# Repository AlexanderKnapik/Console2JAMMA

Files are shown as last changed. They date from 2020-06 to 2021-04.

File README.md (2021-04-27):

# Console2JAMMA

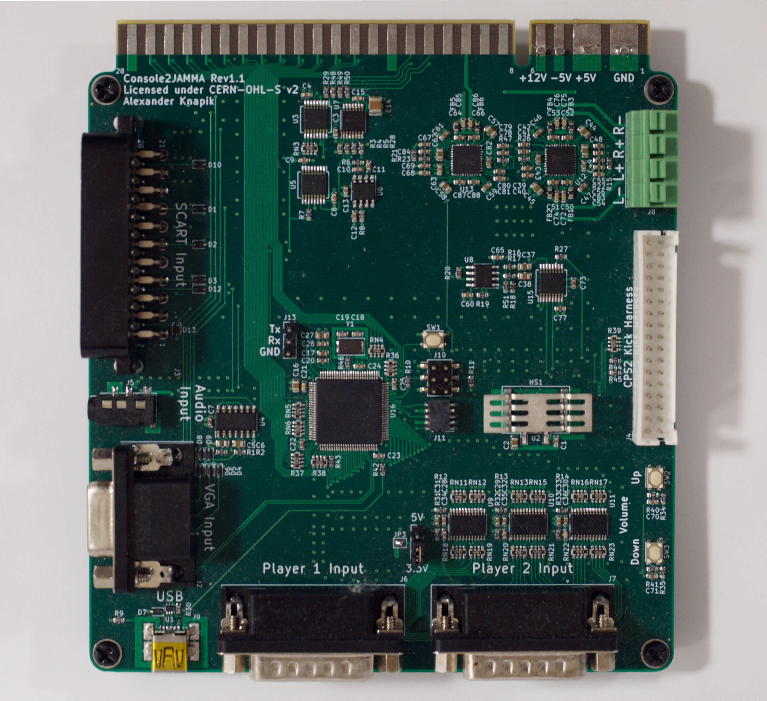
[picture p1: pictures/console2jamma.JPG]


A system to plug video game consoles into a JAMMA arcade system. 

## Features & Goals
- SCART based RGB or VGA video input. Will work perfectly with any natively RGB or modded console, including the Dreamcast. Handles any sync stripping and CSYNC combination for you with amplified video.
- Works with any arcade cabinet supporting standard JAMMA, "CHAMMA" and the CPS2 kick harness.
- Stereo audio input with selectable mono audio combiner for the JAMMA edge, or an external stereo audio output. Amplified for up to 5 Watts of power and can handle standard arcade 4 Ohm or 8 Ohm speakers.
- Can drive 2 player controller ports for 5V or 3.3V based consoles. Will work with any console that has 12 or fewer IO lines with a modded controller port extension.
- Handy spring terminal controller adapters available for those not comfortable with soldering.
- Single player USB output to support PS3 or XBox360 too.

## Progress
This is still heavily a work in progress. I've built up the first hardware prototype and identified some issues that I would like to address. However I am mainly still testing the hardware.

There is also no firmware currently written yet. This is what would need to be addressed next before any further hardware prototypes are designed.

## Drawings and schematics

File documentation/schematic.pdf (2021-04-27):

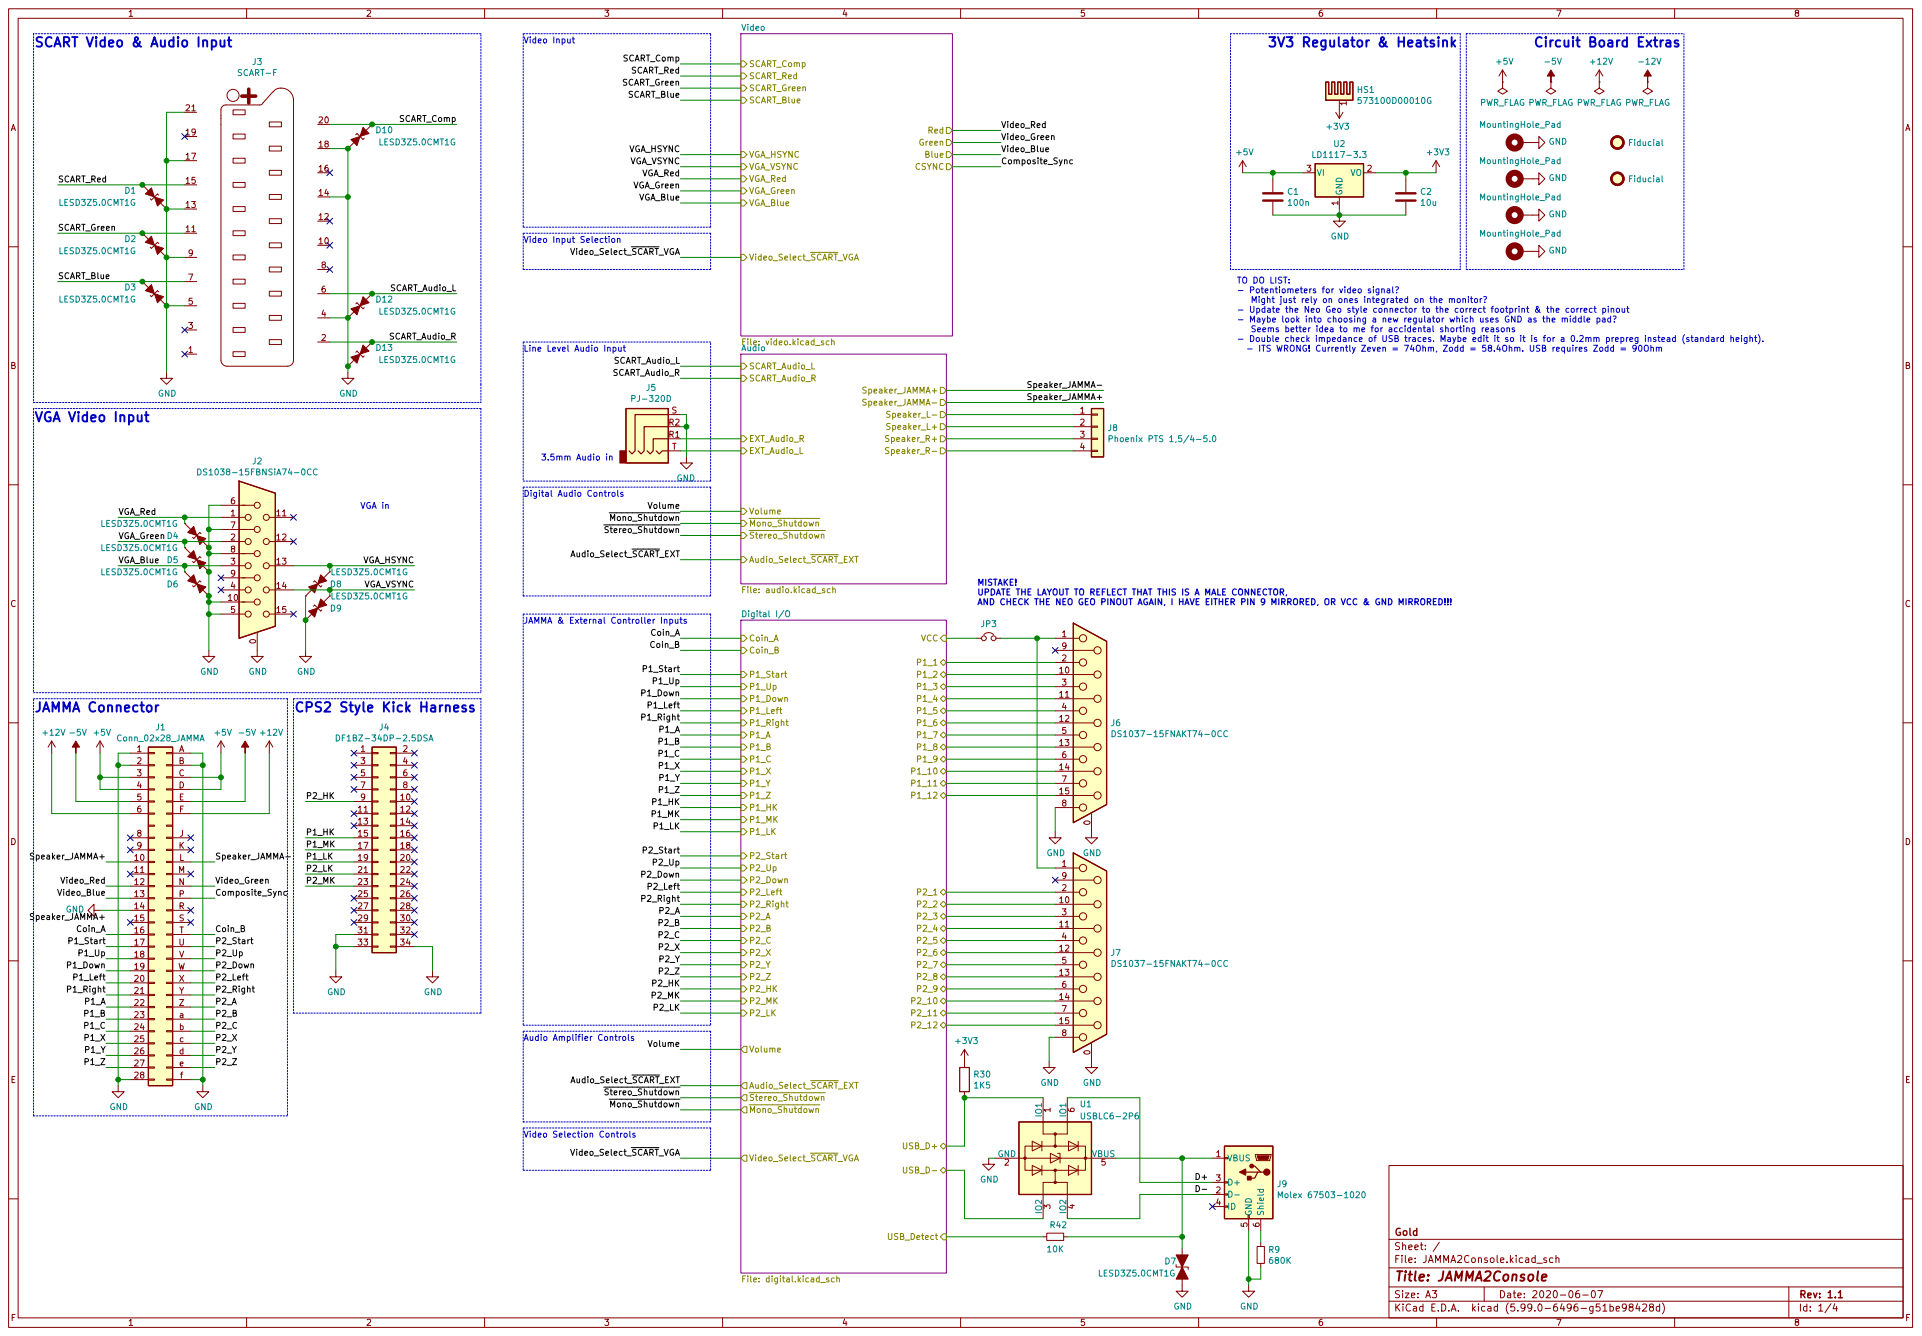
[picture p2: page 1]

TO DO LIST: - Potentiometers for video signal?

Might just rely on ones integrated on the monitor?
- Update the Neo Geo style connector to the correct footprint & the correct pinout
- Maybe look into choosing a new regulator which uses GND as the middle pad?
Seems better idea to me for accidental shorting reasons
- Double check impedance of USB traces. Maybe edit it so it is for a 0.2mm prepreg instead (standard height).
- ITS WRONG! Currently Zeven = 74Ohm, Zodd = 58.4Ohm. USB requires Zodd = 90Ohm

Line Level Audio Input

AND CHECK THE NEO GEO PINOUT AGAIN, I HAVE EITHER PIN 9 MIRRORED, OR VCC & GND MIRRORED!!! Video Selection Controls
JAMMA & External Controller Inputs

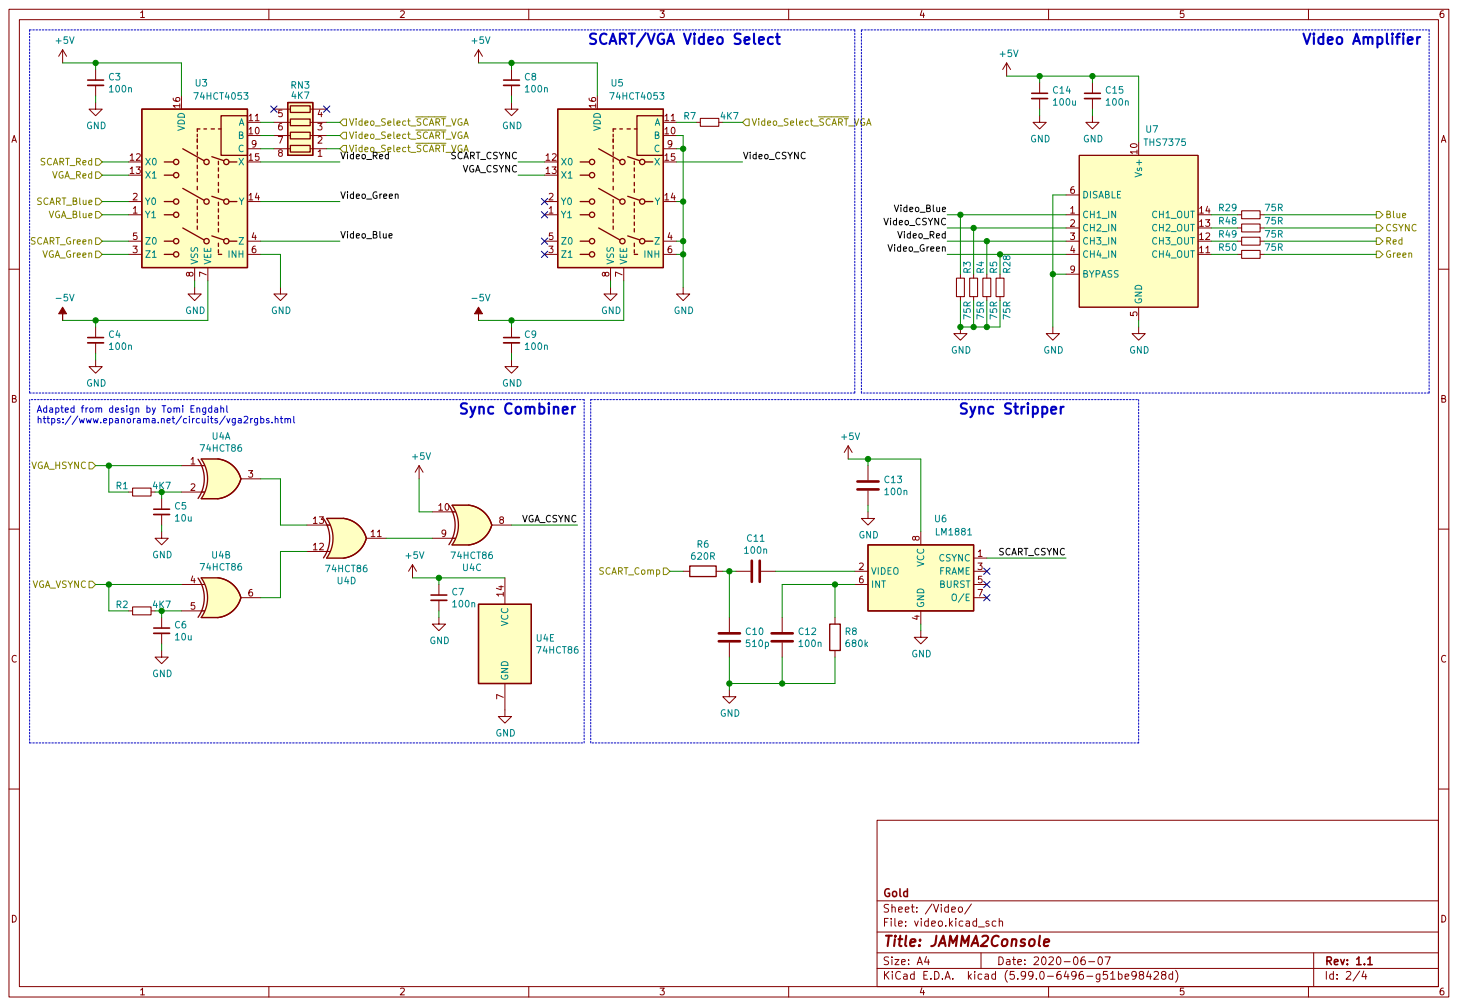
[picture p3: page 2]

SCART/VGA Video Select

Adapted from design by Tomi Engdahl
https://www.epanorama.net/circuits/vga2rgbs.html

File: video.kicad_sch Sheet: /Video/ Gold

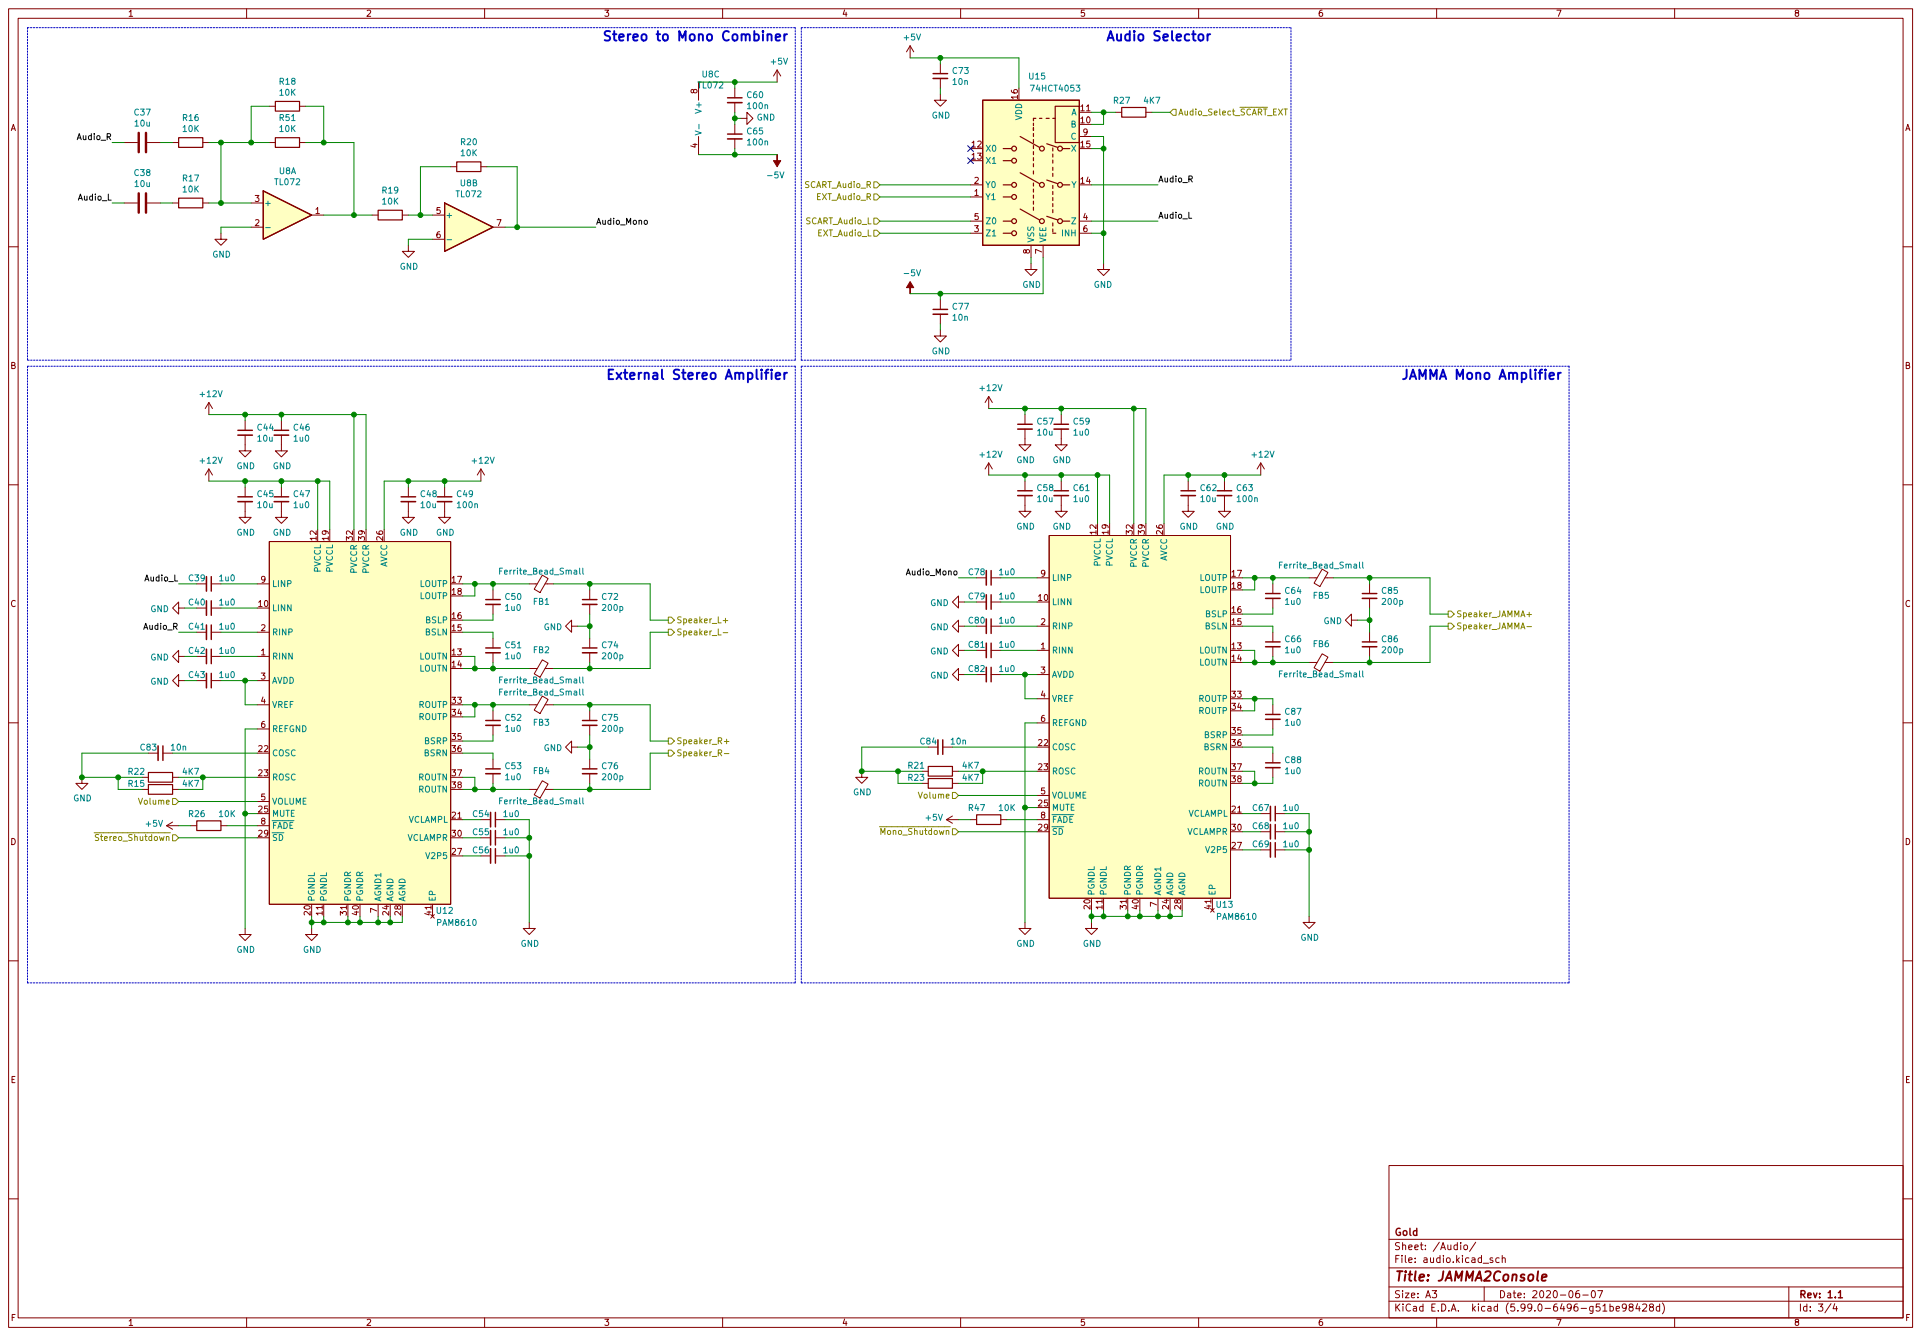
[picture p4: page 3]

File: audio.kicad_sch Sheet: /Audio/ Gold

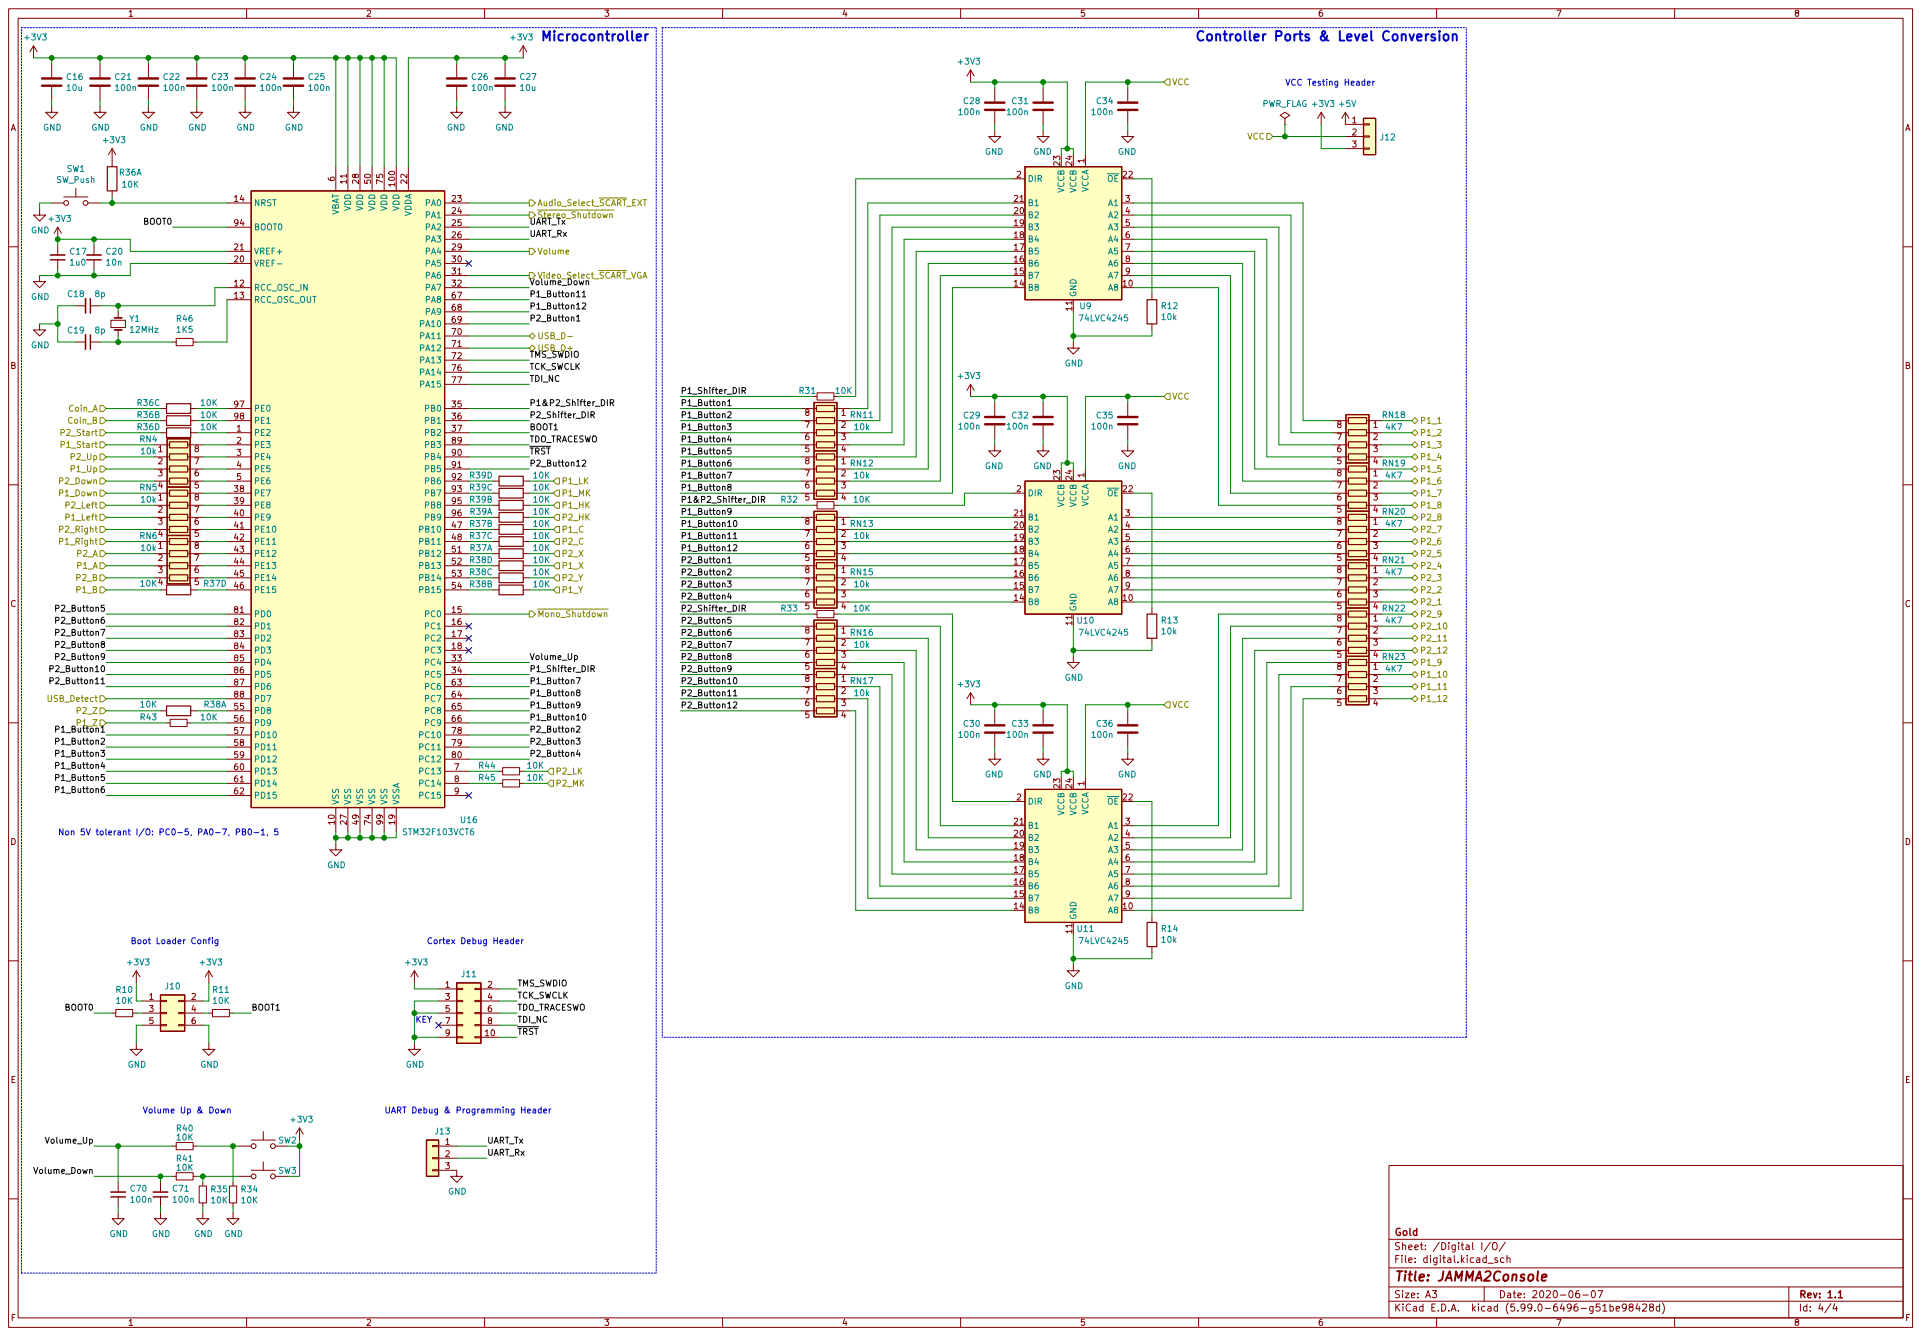
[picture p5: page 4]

Controller Ports & Level Conversion

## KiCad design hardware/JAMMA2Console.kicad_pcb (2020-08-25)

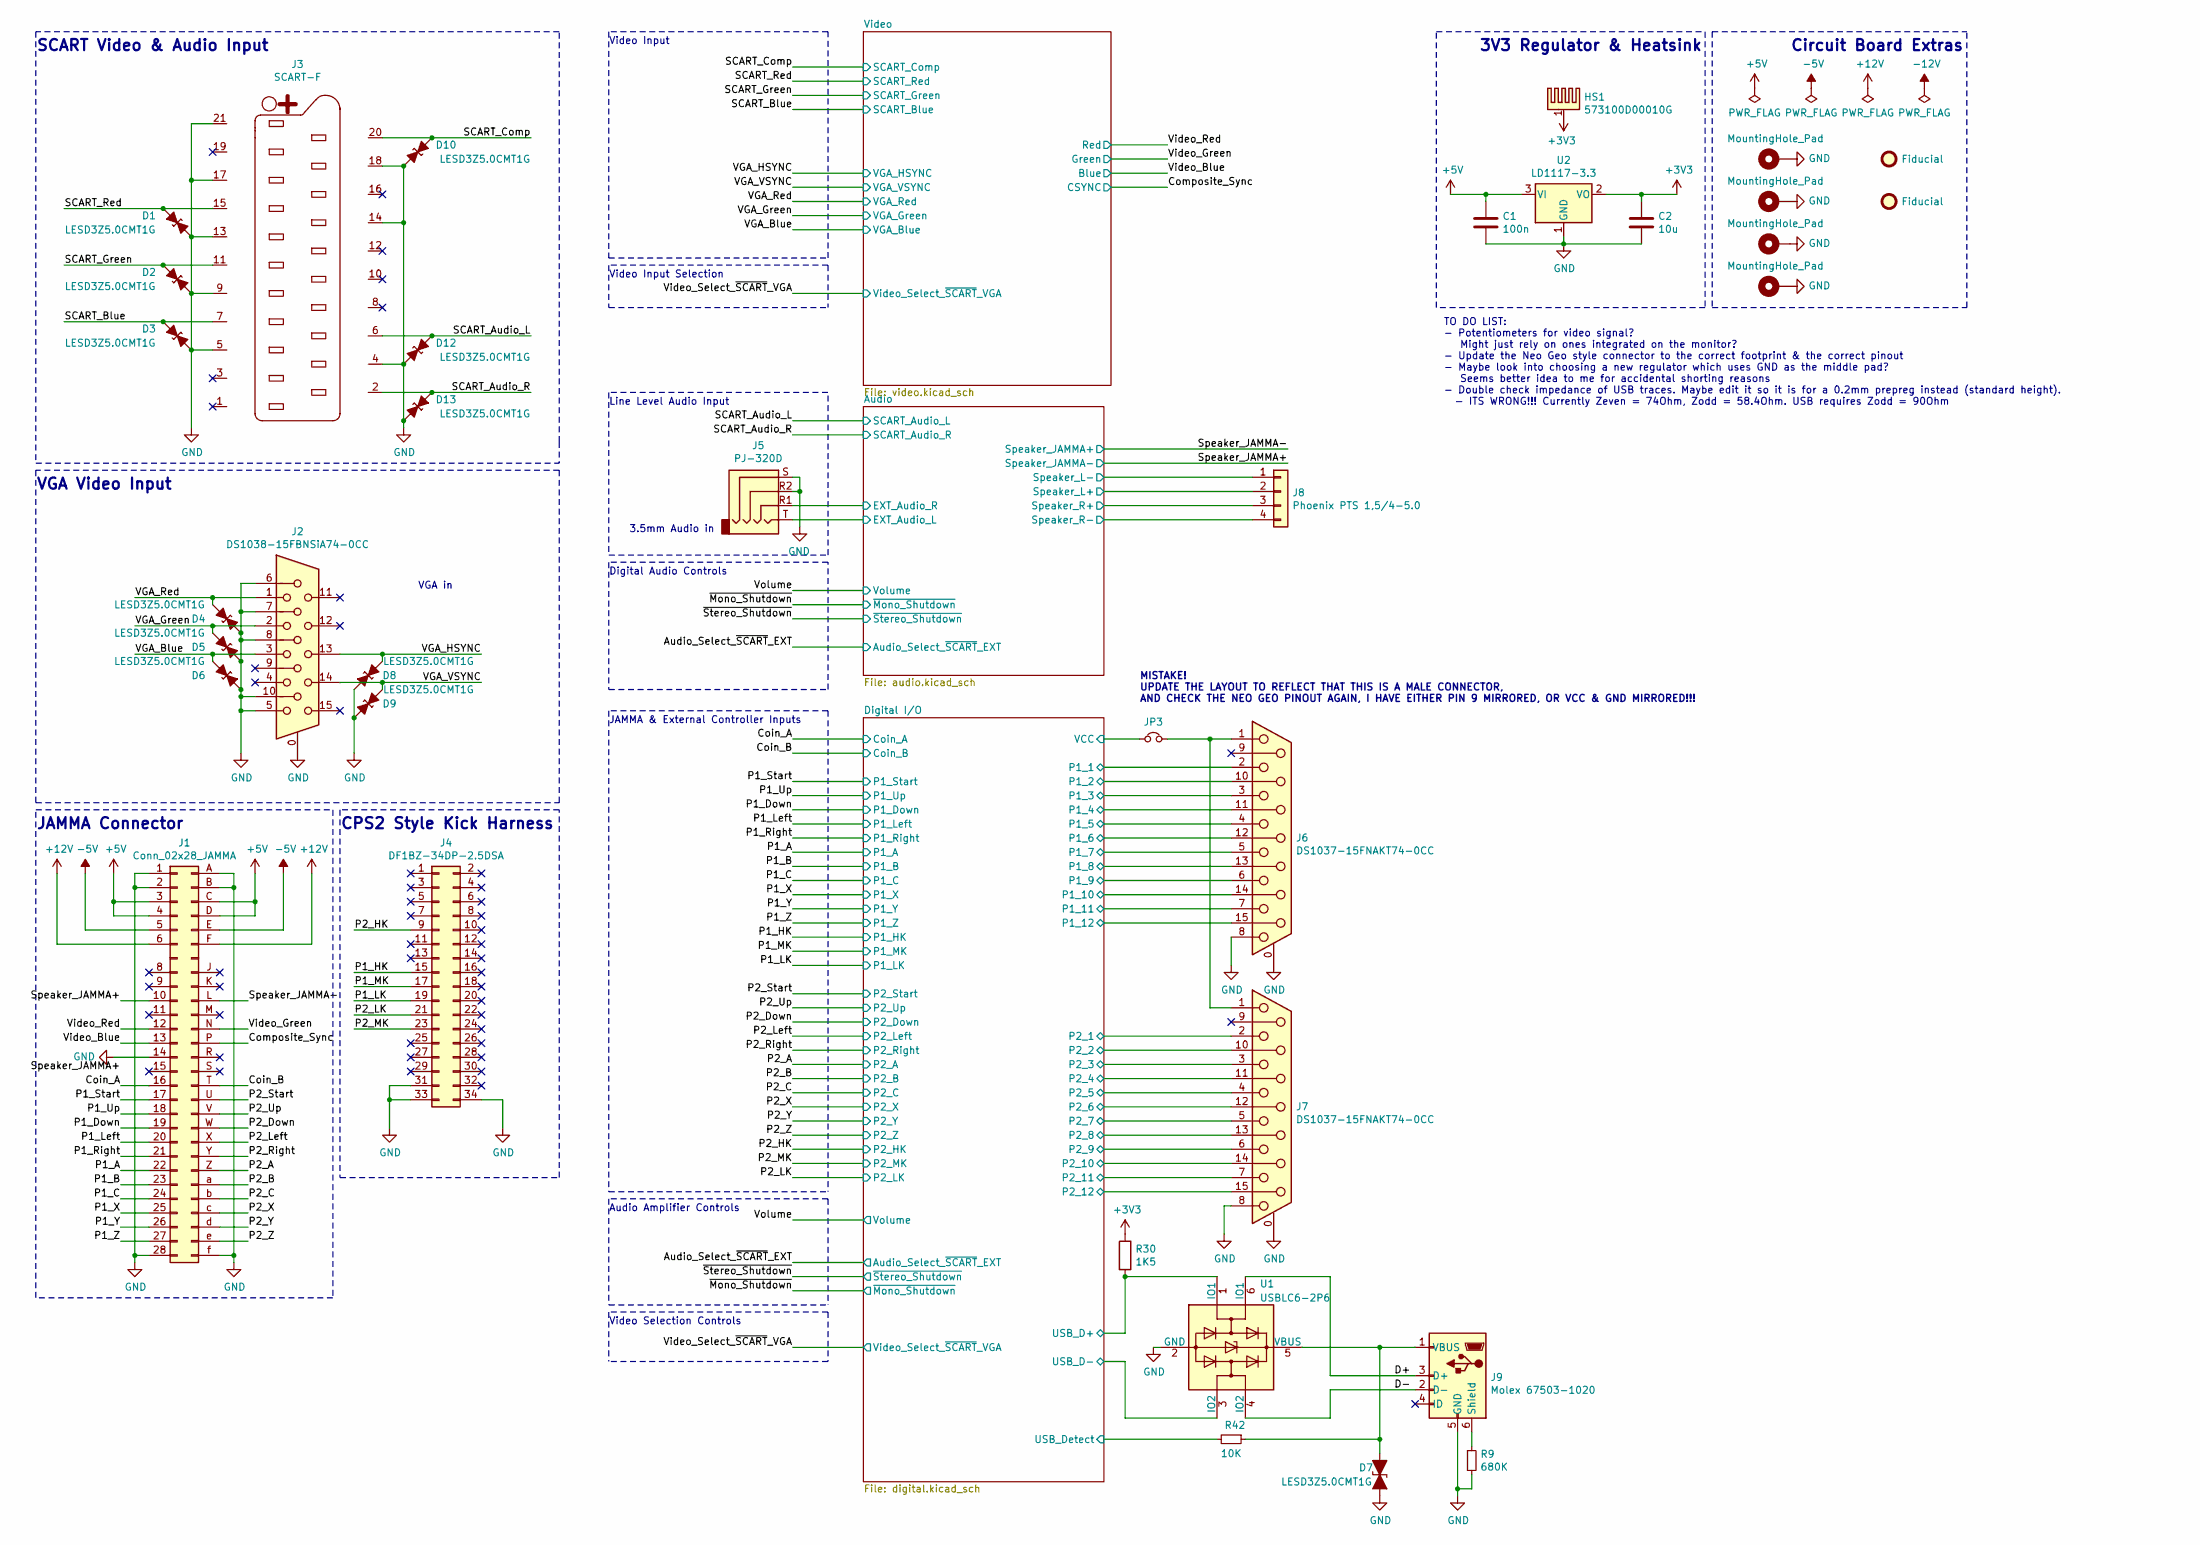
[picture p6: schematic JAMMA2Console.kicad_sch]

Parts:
C1: 100n; C_0603_1608Metric
C2: 10u; C_0805_2012Metric
D1, D2, D3, D4, D5, D6, D7, D8, D9, D10, D12, D13: LESD3Z5.0CMT1G; D_SOD-323
FID1, FID2: Fiducial; Fiducial_0.5mm_Mask1mm
H1, H2, H3, H4: MountingHole_Pad; MountingHole_3.2mm_M3_Pad_Via
HS1: 573100D00010G; Heatsink_AAVID_573100D000x0G_TO-252
J1: Conn_02x28_JAMMA; JAMMA_56_2x28_P3.96mm
J2: DS1038-15FBNSiA74-0CC; DSUB-15-HD_Female_Horizontal_P2.29x1.98mm_EdgePinOffset8.63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
J3: SCART-F; Conn_SCART_CS-107_Right_Angle_Female
J4: DF1BZ-34DP-2.5DSA; Conn_02x17_DF1BZ-34DP-2.5DSA
J5: PJ-320D; Jack_3.5mm_PJ320D_Horizontal
J6, J7: DS1037-15FNAKT74-0CC; DSUB-15_Female_Horizontal_P2.77x2.84mm_EdgePinOffset8.10mm_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
J8: Phoenix PTS 1,5/4-5.0; PhoenixContact_PTS_1,5_4-5_1x4_P5.00mm_Horizontal
J9: Molex 67503-1020; USB_Mini-B_Molex_657031020_Horizontal
JP3: Jumper_NC_Small; SolderJumper-2_P1.3mm_Open_TrianglePad1.0x1.5mm
R9: 680K; R_0603_1608Metric
R30: 1K5; R_0603_1608Metric
R42: 10K; R_0603_1608Metric
U1: USBLC6-2P6; SOT-666
U2: LD1117-3.3; TO-252-2

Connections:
+3V3: C2.1, HS1.1, R30.1, U2.2 (VO); also elsewhere on the board
+5V: C1.1, J1.3, J1.4, J1.C, J1.D, U2.3 (VI); also elsewhere on the board
+12V: J1.6, J1.F; also elsewhere on the board
-5V: J1.5, J1.E; also elsewhere on the board
/Coin_A: J1.16; also elsewhere on the board
/Coin_B: J1.T; also elsewhere on the board
/Composite_Sync: J1.P; also elsewhere on the board
/D+: J9.3 (D+), U1.6 (IO1)
/D-: J9.2 (D-), U1.4 (IO2)
/EXT_Audio_L: J5.T; also elsewhere on the board
/EXT_Audio_R: J5.R1; also elsewhere on the board
/P1_1: J6.2; also elsewhere on the board
/P1_2: J6.10; also elsewhere on the board
/P1_3: J6.3; also elsewhere on the board
/P1_4: J6.11 (P111); also elsewhere on the board
/P1_5: J6.4; also elsewhere on the board
/P1_6: J6.12; also elsewhere on the board
/P1_7: J6.5; also elsewhere on the board
/P1_8: J6.13; also elsewhere on the board
/P1_9: J6.6; also elsewhere on the board
/P1_10: J6.14; also elsewhere on the board
/P1_11: J6.7; also elsewhere on the board
/P1_12: J6.15; also elsewhere on the board
/P1_A: J1.22; also elsewhere on the board
/P1_B: J1.23; also elsewhere on the board
/P1_C: J1.24; also elsewhere on the board
/P1_Down: J1.19; also elsewhere on the board
/P1_HK: J4.15; also elsewhere on the board
/P1_LK: J4.19; also elsewhere on the board
/P1_Left: J1.20; also elsewhere on the board
/P1_MK: J4.17; also elsewhere on the board
/P1_Right: J1.21; also elsewhere on the board
/P1_Start: J1.17; also elsewhere on the board
/P1_Up: J1.18; also elsewhere on the board
/P1_X: J1.25; also elsewhere on the board
/P1_Y: J1.26; also elsewhere on the board
/P1_Z: J1.27; also elsewhere on the board
/P2_1: J7.2; also elsewhere on the board
/P2_2: J7.10; also elsewhere on the board
/P2_3: J7.3; also elsewhere on the board
/P2_4: J7.11 (P111); also elsewhere on the board
/P2_5: J7.4; also elsewhere on the board
/P2_6: J7.12; also elsewhere on the board
/P2_7: J7.5; also elsewhere on the board
/P2_8: J7.13; also elsewhere on the board
/P2_9: J7.6; also elsewhere on the board
/P2_10: J7.14; also elsewhere on the board
/P2_11: J7.7; also elsewhere on the board
/P2_12: J7.15; also elsewhere on the board
/P2_A: J1.Z; also elsewhere on the board
/P2_B: J1.a; also elsewhere on the board
/P2_C: J1.b; also elsewhere on the board
/P2_Down: J1.W; also elsewhere on the board
/P2_HK: J4.9; also elsewhere on the board
/P2_LK: J4.21; also elsewhere on the board
/P2_Left: J1.X; also elsewhere on the board
/P2_MK: J4.23; also elsewhere on the board
/P2_Right: J1.Y; also elsewhere on the board
/P2_Start: J1.U; also elsewhere on the board
/P2_Up: J1.V; also elsewhere on the board
/P2_X: J1.c; also elsewhere on the board
/P2_Y: J1.d; also elsewhere on the board
/P2_Z: J1.e; also elsewhere on the board
/SCART_Audio_L: D12.1, J3.6; also elsewhere on the board
/SCART_Audio_R: D13.1, J3.2; also elsewhere on the board
/SCART_Blue: D3.1, J3.7; also elsewhere on the board
/SCART_Comp: D10.1, J3.20; also elsewhere on the board
/SCART_Green: D2.1, J3.11; also elsewhere on the board
/SCART_Red: D1.1, J3.15; also elsewhere on the board
/Speaker_JAMMA+: J1.10; also elsewhere on the board
/Speaker_JAMMA-: J1.L; also elsewhere on the board
/Speaker_L+: J8.2; also elsewhere on the board
/Speaker_L-: J8.1; also elsewhere on the board
/Speaker_R+: J8.3; also elsewhere on the board
/Speaker_R-: J8.4; also elsewhere on the board
/USB_D+: R30.2, U1.1 (IO1); also elsewhere on the board
/USB_D-: U1.3 (IO2); also elsewhere on the board
/USB_Detect: R42.2; also elsewhere on the board
/VCC: JP3.2; also elsewhere on the board
/VGA_Blue: D6.2, J2.3; also elsewhere on the board
/VGA_Green: D5.2, J2.2; also elsewhere on the board
/VGA_HSYNC: D8.2, J2.13; also elsewhere on the board
/VGA_Red: D4.2, J2.1; also elsewhere on the board
/VGA_VSYNC: D9.2, J2.14; also elsewhere on the board
/Video_Blue: J1.13; also elsewhere on the board
/Video_Green: J1.N; also elsewhere on the board
/Video_Red: J1.12; also elsewhere on the board
GND: C1.2, C2.2, D1.2, D2.2, D3.2, D4.1, D5.1, D6.1, D7.2 (A2), D8.1, D9.1, D10.2, D12.2, D13.2, H1.1, H2.1, H3.1, H4.1, J1.1, J1.2, J1.14, J1.28, J1.A, J1.B, J1.f, J2.0, J2.5, J2.6, J2.7, J2.8, J2.10, J3.4, J3.5, J3.9, J3.13, J3.14, J3.17, J3.18, J3.21, J4.31, J4.33, J4.34, J5.R2, J5.S, J6.0 (PAD), J6.8, J7.0 (PAD), J7.8, J9.5 (GND), R9.2, U1.2 (GND), U2.1 (GND); also elsewhere on the board
unnamed: D7.1 (A1), J9.1 (VBUS), R42.1, U1.5 (VBUS)
unnamed: J6.1, J7.1, JP3.1
unnamed: J9.6 (Shield), R9.1

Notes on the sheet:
SCART Video & Audio Input
VGA Video Input
JAMMA Connector
CPS2 Style Kick Harness
VGA in
Video Input
Video Input Selection
Line Level Audio Input
Digital Audio Controls
JAMMA & External Controller Inputs
Audio Amplifier Controls
Video Selection Controls
3.5mm Audio in
MISTAKE! UPDATE THE LAYOUT TO REFLECT THAT THIS IS A MALE CONNECTOR, AND CHECK THE NEO GEO PINOUT AGAIN, I HAVE EITHER PIN 9 MIRRORED, OR VCC & GND MIRRORED!!!
TO DO LIST: - Potentiometers for video signal? Might just rely on ones integrated on the monitor? - Update the Neo Geo style connector to the correct footprint & the correct pinout - Maybe look into choosing a new regulator which uses GND as the middle pad? Seems better idea to me for accidental sh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
3V3 Regulator & Heatsink
Circuit Board Extras

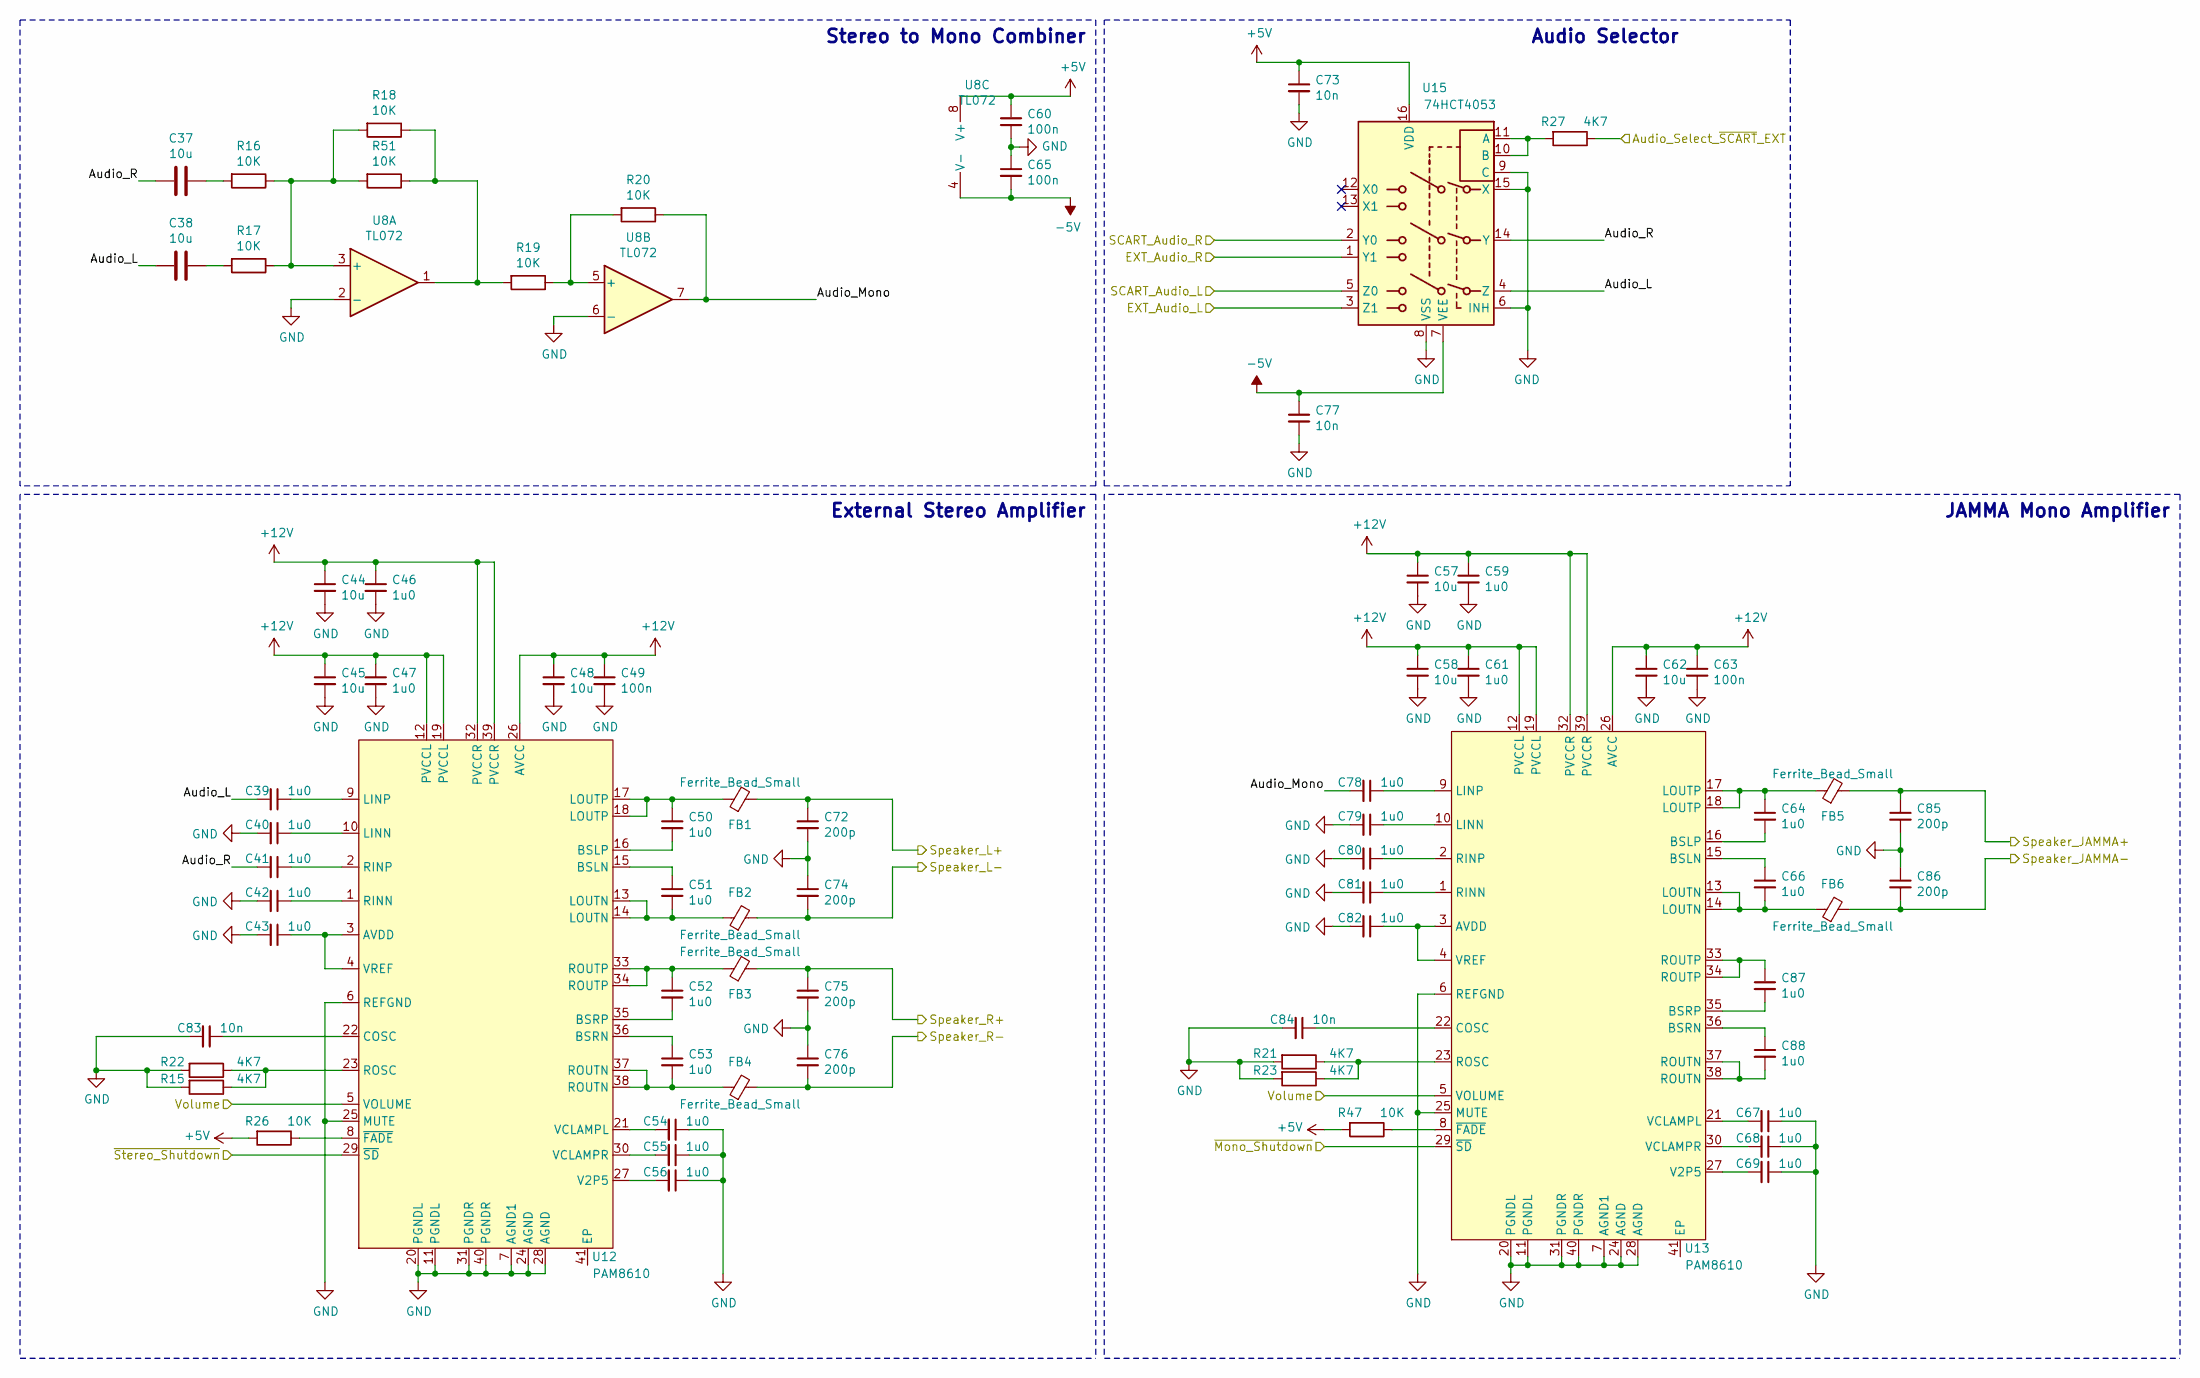
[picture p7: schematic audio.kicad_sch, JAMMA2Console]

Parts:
C37, C38, C44, C45, C48, C57, C58, C62: 10u; C_0805_2012Metric
C39, C40, C41, C42, C43, C46, C47, C50, C51, C52, C53, C54, C55, C56, C59, C61, C64, C66, C67, C68, C69, C78, C79, C80, C81, C82, C87, C88: 1u0; C_0603_1608Metric
C49, C60, C63, C65: 100n; C_0603_1608Metric
C72, C74, C75, C76, C85, C86: 200p; C_0603_1608Metric
C73, C77, C83, C84: 10n; C_0603_1608Metric
FB1, FB2, FB3, FB4, FB5, FB6: Ferrite_Bead_Small; L_0603_1608Metric
R15, R21, R22, R23, R27: 4K7; R_0603_1608Metric
R16, R17, R18, R19, R20, R26, R47, R51: 10K; R_0603_1608Metric
U8: TL072; SOIC-8_3.9x4.9mm_P1.27mm
U12, U13: PAM8610; QFN-40-1EP_6x6mm_P0.5mm_EP4.6x4.6mm_ThermalVias
U15: 74HCT4053; SSOP-16_5.3x6.2mm_P0.65mm

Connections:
+5V: C60.1, C73.1, R26.2, R47.2, U8.8 (V+), U15.16 (VDD); also elsewhere on the board
+12V: C44.1, C45.1, C46.1, C47.1, C48.1, C49.1, C57.1, C58.1, C59.1, C61.1, C62.1, C63.1, U12.12 (PVCCL), U12.19 (PVCCL), U12.26 (AVCC), U12.32 (PVCCR), U12.39 (PVCCR), U13.12 (PVCCL), U13.19 (PVCCL), U13.26 (AVCC), U13.32 (PVCCR), U13.39 (PVCCR); also elsewhere on the board
-5V: C65.2, C77.1, U8.4 (V-), U15.7 (VEE); also elsewhere on the board
/Audio/Audio_L: C38.2, C39.2, U15.4 (Z)
/Audio/Audio_Mono: C78.2, R20.1, U8.7
/Audio/Audio_R: C37.2, C41.2, U15.14 (Y)
/Audio_Select_~SCART~_EXT: R27.1; also elsewhere on the board
/EXT_Audio_L: U15.3 (Z1); also elsewhere on the board
/EXT_Audio_R: U15.1 (Y1); also elsewhere on the board
/SCART_Audio_L: U15.5 (Z0); also elsewhere on the board
/SCART_Audio_R: U15.2 (Y0); also elsewhere on the board
/Speaker_JAMMA+: C86.2, FB6.2; also elsewhere on the board
/Speaker_JAMMA-: C85.1, FB5.2; also elsewhere on the board
/Speaker_L+: C72.1, FB1.2; also elsewhere on the board
/Speaker_L-: C74.2, FB2.2; also elsewhere on the board
/Speaker_R+: C75.1, FB3.2; also elsewhere on the board
/Speaker_R-: C76.2, FB4.2; also elsewhere on the board
/Volume: U12.5 (VOLUME), U13.5 (VOLUME); also elsewhere on the board
/~Mono_Shutdown~: U13.29 (~SD~); also elsewhere on the board
/~Stereo_Shutdown~: U12.29 (~SD~); also elsewhere on the board
GND: C40.2, C42.2, C43.2, C44.2, C45.2, C46.2, C47.2, C48.2, C49.2, C54.1, C55.1, C56.1, C57.2, C58.2, C59.2, C60.2, C61.2, C62.2, C63.2, C65.1, C67.1, C68.1, C69.1, C72.2, C73.2, C74.1, C75.2, C76.1, C77.2, C79.2, C80.2, C81.2, C82.2, C83.2, C84.2, C85.2, C86.1, R15.2, R21.2, R22.2, R23.2, U8.2 (-), U8.6 (-), U12.6 (REFGND), U12.7 (AGND1), U12.11 (PGNDL), U12.20 (PGNDL), U12.24 (AGND), U12.25 (MUTE), U12.28 (AGND), U12.31 (PGNDR), U12.40 (PGNDR), U13.6 (REFGND), U13.7 (AGND1), U13.11 (PGNDL), U13.20 (PGNDL), U13.24 (AGND), U13.25 (MUTE), U13.28 (AGND), U13.31 (PGNDR), U13.40 (PGNDR), U15.6 (INH), U15.8 (VSS), U15.9 (C), U15.15 (X); also elsewhere on the board
unnamed: C37.1, R16.2
unnamed: C38.1, R17.2
unnamed: C39.1, U12.9 (LINP)
unnamed: C40.1, U12.10 (LINN)
unnamed: C41.1, U12.2 (RINP)
unnamed: C42.1, U12.1 (RINN)
unnamed: C43.1, U12.3 (AVDD), U12.4 (VREF)
unnamed: C50.1, FB1.1, U12.17 (LOUTP), U12.18 (LOUTP)
unnamed: C50.2, U12.16 (BSLP)
unnamed: C51.1, U12.15 (BSLN)
unnamed: C51.2, FB2.1, U12.13 (LOUTN), U12.14 (LOUTN)
unnamed: C52.1, FB3.1, U12.33 (ROUTP), U12.34 (ROUTP)
unnamed: C52.2, U12.35 (BSRP)
unnamed: C53.1, U12.36 (BSRN)
unnamed: C53.2, FB4.1, U12.37 (ROUTN), U12.38 (ROUTN)
unnamed: C54.2, U12.21 (VCLAMPL)
unnamed: C55.2, U12.30 (VCLAMPR)
unnamed: C56.2, U12.27 (V2P5)
unnamed: C64.1, FB5.1, U13.17 (LOUTP), U13.18 (LOUTP)
unnamed: C64.2, U13.16 (BSLP)
unnamed: C66.1, U13.15 (BSLN)
unnamed: C66.2, FB6.1, U13.13 (LOUTN), U13.14 (LOUTN)
unnamed: C67.2, U13.21 (VCLAMPL)
unnamed: C68.2, U13.30 (VCLAMPR)
unnamed: C69.2, U13.27 (V2P5)
unnamed: C78.1, U13.9 (LINP)
unnamed: C79.1, U13.10 (LINN)
unnamed: C80.1, U13.2 (RINP)
unnamed: C81.1, U13.1 (RINN)
unnamed: C82.1, U13.3 (AVDD), U13.4 (VREF)
unnamed: C83.1, U12.22 (COSC)
unnamed: C84.1, U13.22 (COSC)
unnamed: C87.1, U13.33 (ROUTP), U13.34 (ROUTP)
unnamed: C87.2, U13.35 (BSRP)
unnamed: C88.1, U13.36 (BSRN)
unnamed: C88.2, U13.37 (ROUTN), U13.38 (ROUTN)
unnamed: R15.1, R22.1, U12.23 (ROSC)
unnamed: R16.1, R17.1, R18.2, R51.2, U8.3 (+)
unnamed: R18.1, R19.2, R51.1, U8.1
unnamed: R19.1, R20.2, U8.5 (+)
unnamed: R21.1, R23.1, U13.23 (ROSC)
unnamed: R26.1, U12.8 (~FADE~)
unnamed: R27.2, U15.10 (B), U15.11 (A)
unnamed: R47.1, U13.8 (~FADE~)

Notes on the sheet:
Stereo to Mono Combiner
External Stereo Amplifier
Audio Selector
JAMMA Mono Amplifier

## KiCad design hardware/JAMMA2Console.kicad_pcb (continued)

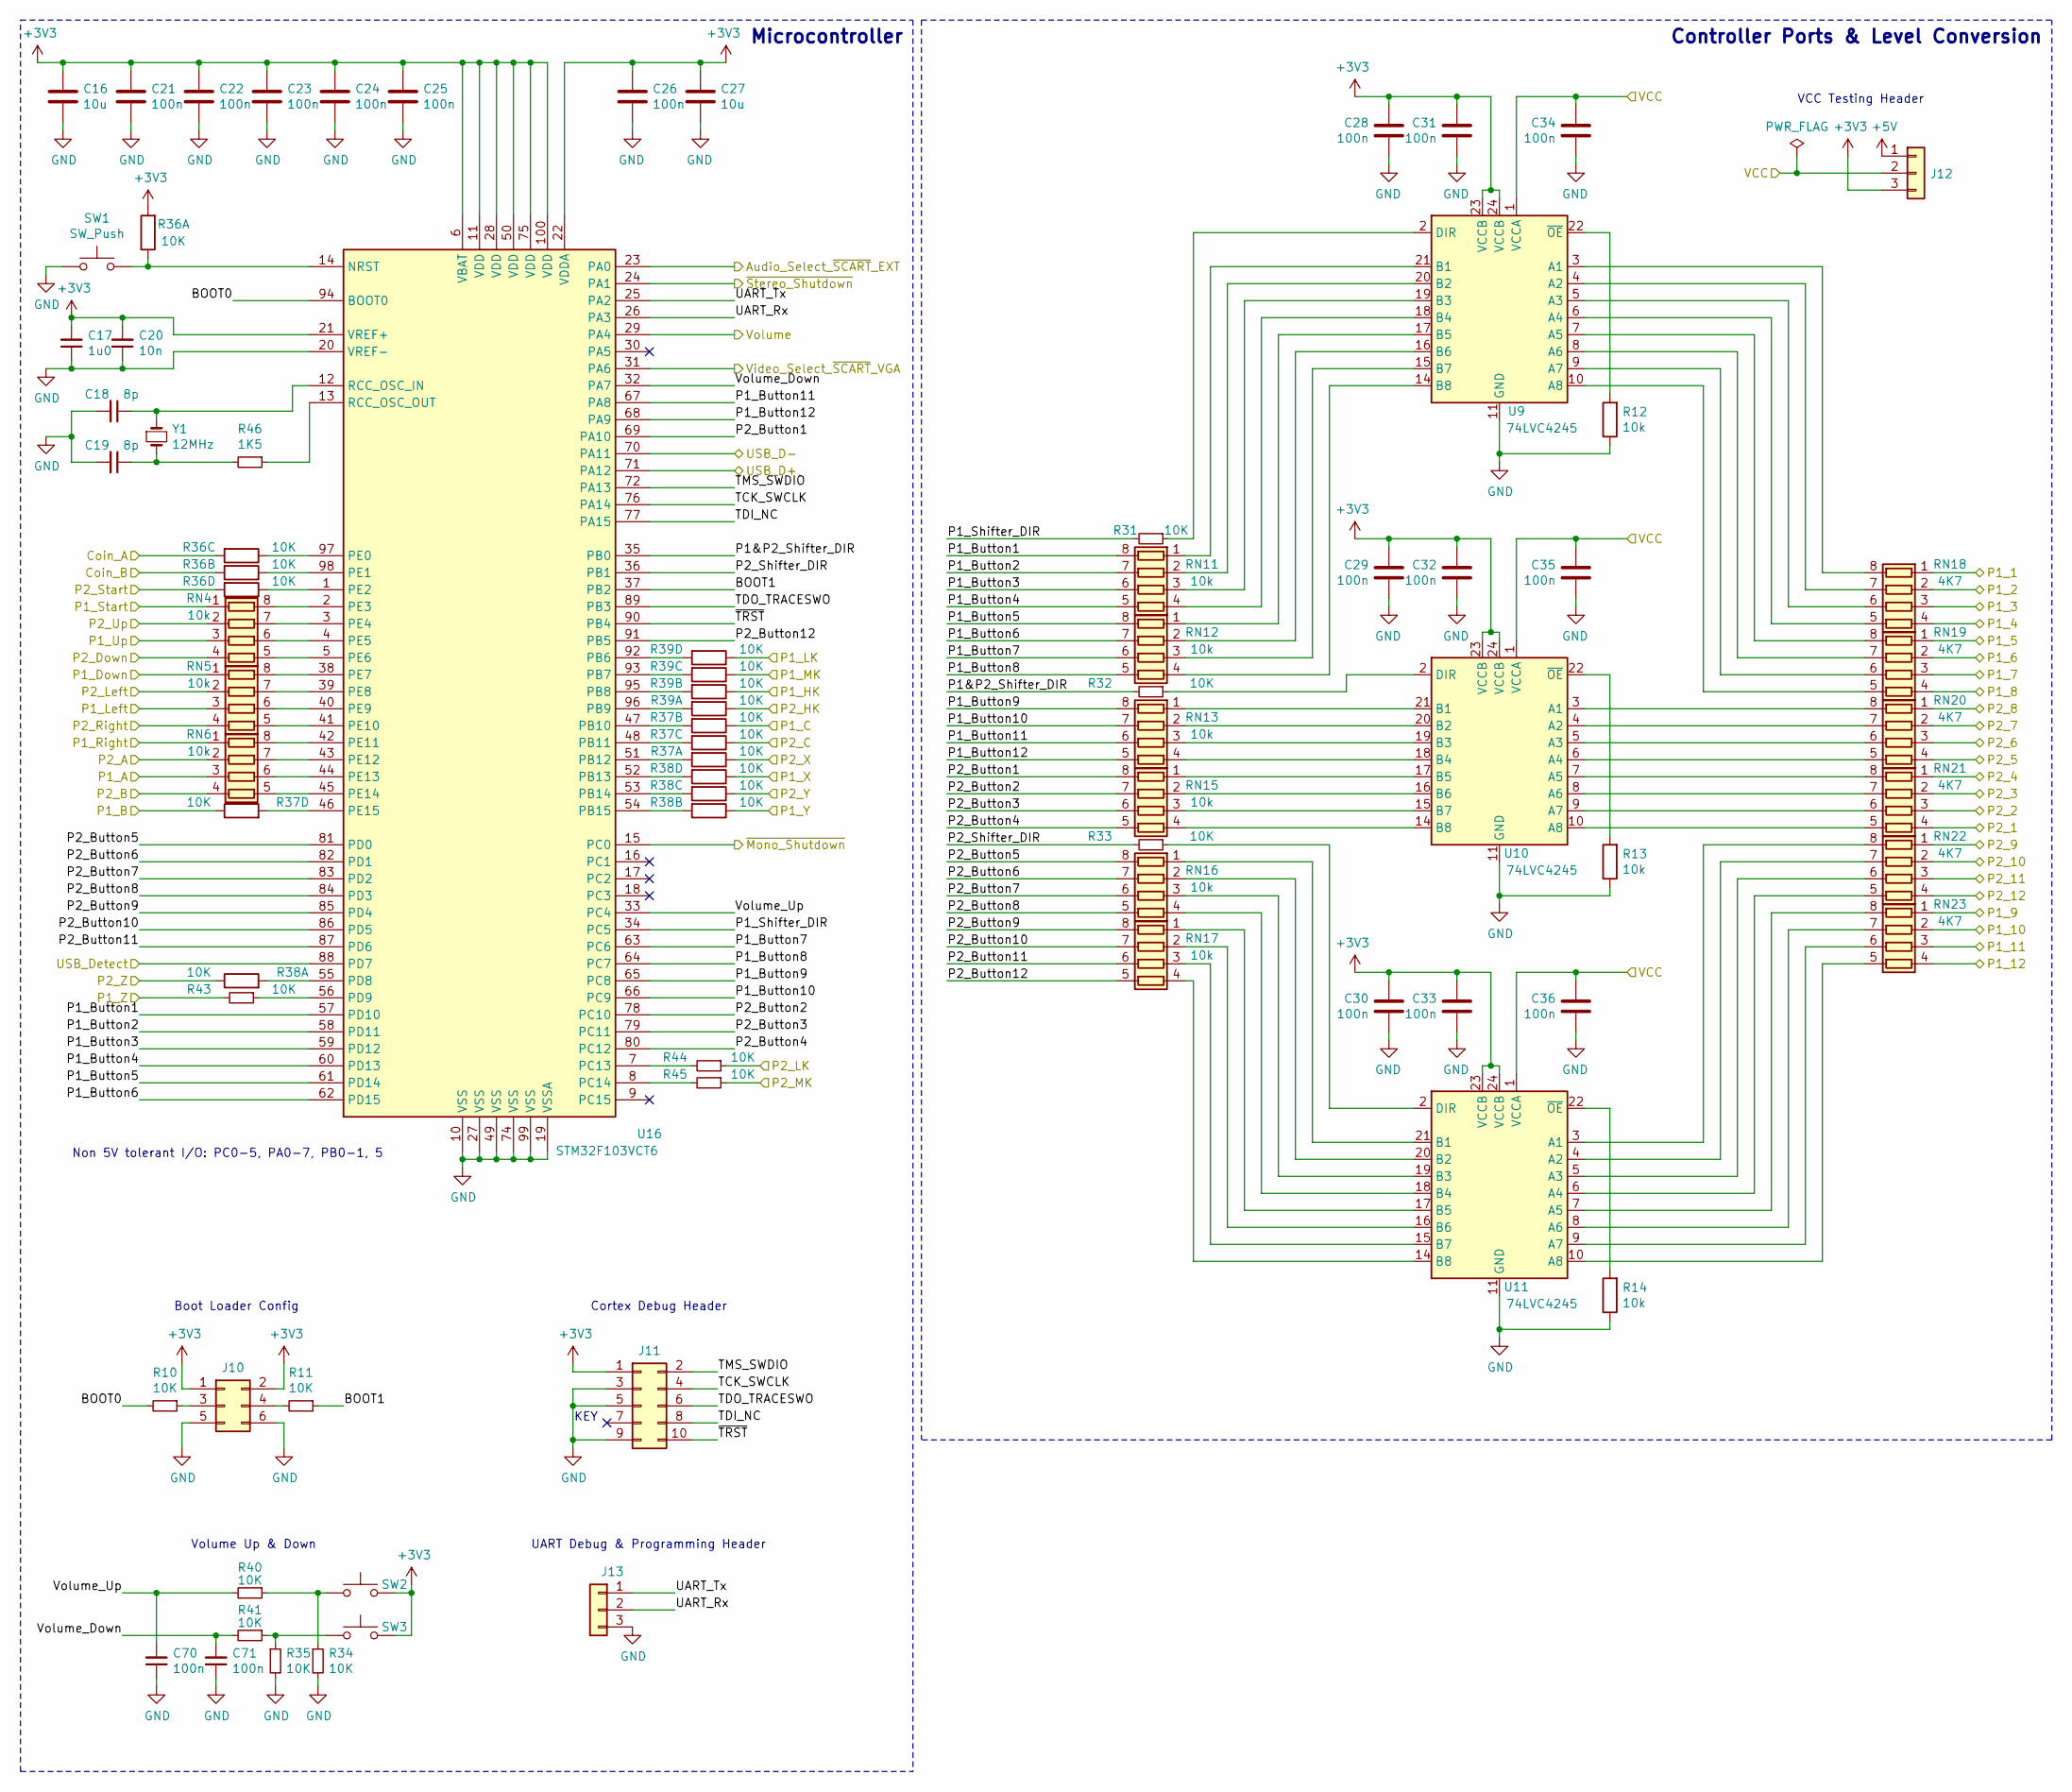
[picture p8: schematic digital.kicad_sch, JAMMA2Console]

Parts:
C16, C27: 10u; C_0805_2012Metric
C17: 1u0; C_0603_1608Metric
C18, C19: 8p; C_0603_1608Metric
C20: 10n; C_0603_1608Metric
C21, C22, C23, C24, C25, C26, C28, C29, C30, C31, C32, C33, C34, C35, C36, C70, C71: 100n; C_0603_1608Metric
J10: Conn_02x03_Odd_Even; PinHeader_2x03_P2.54mm_Vertical_SMD
J11: Conn_02x05_Odd_Even; PinHeader_2x05_P1.27mm_Vertical_SMD
J12, J13: Conn_01x03; PinHeader_1x03_P2.54mm_Vertical
R10, R11, R31, R32, R33, R34, R35, R40, R41, R43, R44, R45: 10K; R_0603_1608Metric
R12, R13, R14: 10k; R_0603_1608Metric
R36, R37, R38, R39: 10K; R_Array_Convex_4x0603
R46: 1K5; R_0603_1608Metric
RN4, RN5, RN6, RN11, RN12, RN13, RN15, RN16, RN17: 10k; R_Array_Convex_4x0603
RN18, RN19, RN20, RN21, RN22, RN23: 4K7; R_Array_Convex_4x0603
SW1, SW2, SW3: SW_Push; SW_Push_SPST_NO_Alps_SKRP
U9, U10, U11: 74LVC4245; TSSOP-24_4.4x7.8mm_P0.65mm
U16: STM32F103VCT6; LQFP-100_14x14mm_P0.5mm
Y1: 12MHz; Crystal_SMD_5032-2Pin_5.0x3.2mm

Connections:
+3V3: C16.1, C17.2, C20.2, C21.1, C22.1, C23.1, C24.1, C25.1, C26.1, C27.1, C28.1, C29.1, C30.1, C31.1, C32.1, C33.1, J10.1, J10.2, J11.1, J12.3, R36.1, SW2.2, SW3.2, U9.23 (VCCB), U9.24 (VCCB), U10.23 (VCCB), U10.24 (VCCB), U11.23 (VCCB), U11.24 (VCCB), U16.6 (VBAT), U16.11 (VDD), U16.21 (VREF+), U16.22 (VDDA), U16.28 (VDD), U16.50 (VDD), U16.75 (VDD), U16.100 (VDD); also elsewhere on the board
+5V: J12.1; also elsewhere on the board
/Audio_Select_~SCART~_EXT: U16.23 (PA0); also elsewhere on the board
/Coin_A: R36.3; also elsewhere on the board
/Coin_B: R36.2; also elsewhere on the board
/Digital I/O/BOOT0: R10.2, U16.94 (BOOT0)
/Digital I/O/BOOT1: R11.1, U16.37 (PB2)
/Digital I/O/P1&P2_Shifter_DIR: R32.2, U16.35 (PB0)
/Digital I/O/P1_Button1: RN11.8 (R1.2), U16.57 (PD10)
/Digital I/O/P1_Button2: RN11.7 (R2.2), U16.58 (PD11)
/Digital I/O/P1_Button3: RN11.6 (R3.2), U16.59 (PD12)
/Digital I/O/P1_Button4: RN11.5 (R4.2), U16.60 (PD13)
/Digital I/O/P1_Button5: RN12.8 (R1.2), U16.61 (PD14)
/Digital I/O/P1_Button6: RN12.7 (R2.2), U16.62 (PD15)
/Digital I/O/P1_Button7: RN12.6 (R3.2), U16.63 (PC6)
/Digital I/O/P1_Button8: RN12.5 (R4.2), U16.64 (PC7)
/Digital I/O/P1_Button9: RN13.8 (R1.2), U16.65 (PC8)
/Digital I/O/P1_Button10: RN13.7 (R2.2), U16.66 (PC9)
/Digital I/O/P1_Button11: RN13.6 (R3.2), U16.67 (PA8)
/Digital I/O/P1_Button12: RN13.5 (R4.2), U16.68 (PA9)
/Digital I/O/P1_Shifter_DIR: R31.2, U16.34 (PC5)
/Digital I/O/P2_Button1: RN15.8 (R1.2), U16.69 (PA10)
/Digital I/O/P2_Button2: RN15.7 (R2.2), U16.78 (PC10)
/Digital I/O/P2_Button3: RN15.6 (R3.2), U16.79 (PC11)
/Digital I/O/P2_Button4: RN15.5 (R4.2), U16.80 (PC12)
/Digital I/O/P2_Button5: RN16.8 (R1.2), U16.81 (PD0)
/Digital I/O/P2_Button6: RN16.7 (R2.2), U16.82 (PD1)
/Digital I/O/P2_Button7: RN16.6 (R3.2), U16.83 (PD2)
/Digital I/O/P2_Button8: RN16.5 (R4.2), U16.84 (PD3)
/Digital I/O/P2_Button9: RN17.8 (R1.2), U16.85 (PD4)
/Digital I/O/P2_Button10: RN17.7 (R2.2), U16.86 (PD5)
/Digital I/O/P2_Button11: RN17.6 (R3.2), U16.87 (PD6)
/Digital I/O/P2_Button12: RN17.5 (R4.2), U16.91 (PB5)
/Digital I/O/P2_Shifter_DIR: R33.2, U16.36 (PB1)
/Digital I/O/TCK_SWCLK: J11.4, U16.76 (PA14)
/Digital I/O/TDI_NC: J11.8, U16.77 (PA15)
/Digital I/O/TDO_TRACESWO: J11.6, U16.89 (PB3)
/Digital I/O/TMS_SWDIO: J11.2, U16.72 (PA13)
/Digital I/O/UART_Rx: J13.2, U16.26 (PA3)
/Digital I/O/UART_Tx: J13.1, U16.25 (PA2)
/Digital I/O/Volume_Down: C71.2, R41.2, U16.32 (PA7)
/Digital I/O/Volume_Up: C70.2, R40.2, U16.33 (PC4)
/Digital I/O/~TRST~: J11.10, U16.90 (PB4)
/P1_1: RN18.1 (R1.1); also elsewhere on the board
/P1_2: RN18.2 (R2.1); also elsewhere on the board
/P1_3: RN18.3 (R3.1); also elsewhere on the board
/P1_4: RN18.4 (R4.1); also elsewhere on the board
/P1_5: RN19.1 (R1.1); also elsewhere on the board
/P1_6: RN19.2 (R2.1); also elsewhere on the board
/P1_7: RN19.3 (R3.1); also elsewhere on the board
/P1_8: RN19.4 (R4.1); also elsewhere on the board
/P1_9: RN23.1 (R1.1); also elsewhere on the board
/P1_10: RN23.2 (R2.1); also elsewhere on the board
/P1_11: RN23.3 (R3.1); also elsewhere on the board
/P1_12: RN23.4 (R4.1); also elsewhere on the board
/P1_A: RN6.3 (R3.1); also elsewhere on the board
/P1_B: R37.5; also elsewhere on the board
/P1_C: R37.7; also elsewhere on the board
/P1_Down: RN5.1 (R1.1); also elsewhere on the board
/P1_HK: R39.7; also elsewhere on the board
/P1_LK: R39.5; also elsewhere on the board
/P1_Left: RN5.3 (R3.1); also elsewhere on the board
/P1_MK: R39.6; also elsewhere on the board
/P1_Right: RN6.1 (R1.1); also elsewhere on the board
/P1_Start: RN4.1 (R1.1); also elsewhere on the board
/P1_Up: RN4.3 (R3.1); also elsewhere on the board
/P1_X: R38.5; also elsewhere on the board
/P1_Y: R38.7; also elsewhere on the board
/P1_Z: R43.2; also elsewhere on the board
/P2_1: RN21.4 (R4.1); also elsewhere on the board
/P2_2: RN21.3 (R3.1); also elsewhere on the board
/P2_3: RN21.2 (R2.1); also elsewhere on the board
/P2_4: RN21.1 (R1.1); also elsewhere on the board
/P2_5: RN20.4 (R4.1); also elsewhere on the board
/P2_6: RN20.3 (R3.1); also elsewhere on the board
/P2_7: RN20.2 (R2.1); also elsewhere on the board
/P2_8: RN20.1 (R1.1); also elsewhere on the board
/P2_9: RN22.1 (R1.1); also elsewhere on the board
/P2_10: RN22.2 (R2.1); also elsewhere on the board
/P2_11: RN22.3 (R3.1); also elsewhere on the board
/P2_12: RN22.4 (R4.1); also elsewhere on the board
/P2_A: RN6.2 (R2.1); also elsewhere on the board
/P2_B: RN6.4 (R4.1); also elsewhere on the board
/P2_C: R37.6; also elsewhere on the board
/P2_Down: RN4.4 (R4.1); also elsewhere on the board
/P2_HK: R39.8; also elsewhere on the board
/P2_LK: R44.1; also elsewhere on the board
/P2_Left: RN5.2 (R2.1); also elsewhere on the board
/P2_MK: R45.1; also elsewhere on the board
/P2_Right: RN5.4 (R4.1); also elsewhere on the board
/P2_Start: R36.4; also elsewhere on the board
/P2_Up: RN4.2 (R2.1); also elsewhere on the board
/P2_X: R37.8; also elsewhere on the board
/P2_Y: R38.6; also elsewhere on the board
/P2_Z: R38.8; also elsewhere on the board
/USB_D+: U16.71 (PA12); also elsewhere on the board
/USB_D-: U16.70 (PA11); also elsewhere on the board
/USB_Detect: U16.88 (PD7); also elsewhere on the board
/VCC: C34.1, C35.1, C36.1, J12.2, U9.1 (VCCA), U10.1 (VCCA), U11.1 (VCCA); also elsewhere on the board
/Video_Select_~SCART~_VGA: U16.31 (PA6); also elsewhere on the board
/Volume: U16.29 (PA4); also elsewhere on the board
/~Mono_Shutdown~: U16.15 (PC0); also elsewhere on the board
/~Stereo_Shutdown~: U16.24 (PA1); also elsewhere on the board
GND: C16.2, C17.1, C18.2, C19.2, C20.1, C21.2, C22.2, C23.2, C24.2, C25.2, C26.2, C27.2, C28.2, C29.2, C30.2, C31.2, C32.2, C33.2, C34.2, C35.2, C36.2, C70.1, C71.1, J10.5, J10.6, J11.3, J11.5, J11.9, J13.3, R12.1, R13.1, R14.1, R34.2, R35.2, SW1.1, U9.11 (GND), U9.12 (GND), U9.13 (GND), U10.11 (GND), U10.12 (GND), U10.13 (GND), U11.11 (GND), U11.12 (GND), U11.13 (GND), U16.10 (VSS), U16.19 (VSSA), U16.20 (VREF-), U16.27 (VSS), U16.49 (VSS), U16.74 (VSS), U16.99 (VSS); also elsewhere on the board
unnamed: C18.1, U16.12 (RCC_OSC_IN), Y1.1
unnamed: C19.1, R46.2, Y1.2
unnamed: J10.3, R10.1
unnamed: J10.4, R11.2
unnamed: R12.2, U9.22 (~OE)
unnamed: R13.2, U10.22 (~OE)
unnamed: R14.2, U11.22 (~OE)
unnamed: R31.1, U9.2 (DIR)
unnamed: R32.1, U10.2 (DIR)
unnamed: R33.1, U11.2 (DIR)
unnamed: R34.1, R40.1, SW2.1
unnamed: R35.1, R41.1, SW3.1
unnamed: R36.5, U16.1 (PE2)
unnamed: R36.6, U16.97 (PE0)
unnamed: R36.7, U16.98 (PE1)
unnamed: R36.8, SW1.2, U16.14 (NRST)
unnamed: R37.1, U16.51 (PB12)
unnamed: R37.2, U16.47 (PB10)
unnamed: R37.3, U16.48 (PB11)
unnamed: R37.4, U16.46 (PE15)
unnamed: R38.1, U16.55 (PD8)
unnamed: R38.2, U16.54 (PB15)
unnamed: R38.3, U16.53 (PB14)
unnamed: R38.4, U16.52 (PB13)
unnamed: R39.1, U16.96 (PB9)
unnamed: R39.2, U16.95 (PB8)
unnamed: R39.3, U16.93 (PB7)
unnamed: R39.4, U16.92 (PB6)
unnamed: R43.1, U16.56 (PD9)
unnamed: R44.2, U16.7 (PC13)
unnamed: R45.2, U16.8 (PC14)
unnamed: R46.1, U16.13 (RCC_OSC_OUT)
unnamed: RN4.5 (R4.2), U16.5 (PE6)
unnamed: RN4.6 (R3.2), U16.4 (PE5)
unnamed: RN4.7 (R2.2), U16.3 (PE4)
unnamed: RN4.8 (R1.2), U16.2 (PE3)
unnamed: RN5.5 (R4.2), U16.41 (PE10)
unnamed: RN5.6 (R3.2), U16.40 (PE9)
unnamed: RN5.7 (R2.2), U16.39 (PE8)
unnamed: RN5.8 (R1.2), U16.38 (PE7)
unnamed: RN6.5 (R4.2), U16.45 (PE14)
unnamed: RN6.6 (R3.2), U16.44 (PE13)
unnamed: RN6.7 (R2.2), U16.43 (PE12)
unnamed: RN6.8 (R1.2), U16.42 (PE11)
unnamed: RN11.1 (R1.1), U9.21 (B1)
unnamed: RN11.2 (R2.1), U9.20 (B2)
unnamed: RN11.3 (R3.1), U9.19 (B3)
unnamed: RN11.4 (R4.1), U9.18 (B4)
unnamed: RN12.1 (R1.1), U9.17 (B5)
unnamed: RN12.2 (R2.1), U9.16 (B6)
unnamed: RN12.3 (R3.1), U9.15 (B7)
unnamed: RN12.4 (R4.1), U9.14 (B8)
unnamed: RN13.1 (R1.1), U10.21 (B1)
unnamed: RN13.2 (R2.1), U10.20 (B2)
unnamed: RN13.3 (R3.1), U10.19 (B3)
unnamed: RN13.4 (R4.1), U10.18 (B4)
unnamed: RN15.1 (R1.1), U10.17 (B5)
unnamed: RN15.2 (R2.1), U10.16 (B6)
unnamed: RN15.3 (R3.1), U10.15 (B7)
unnamed: RN15.4 (R4.1), U10.14 (B8)
unnamed: RN16.1 (R1.1), U11.21 (B1)
unnamed: RN16.2 (R2.1), U11.20 (B2)
unnamed: RN16.3 (R3.1), U11.19 (B3)
unnamed: RN16.4 (R4.1), U11.18 (B4)
unnamed: RN17.1 (R1.1), U11.17 (B5)
unnamed: RN17.2 (R2.1), U11.16 (B6)
unnamed: RN17.3 (R3.1), U11.15 (B7)
unnamed: RN17.4 (R4.1), U11.14 (B8)
unnamed: RN18.5 (R4.2), U9.6 (A4)
unnamed: RN18.6 (R3.2), U9.5 (A3)
unnamed: RN18.7 (R2.2), U9.4 (A2)
unnamed: RN18.8 (R1.2), U9.3 (A1)
unnamed: RN19.5 (R4.2), U9.10 (A8)
unnamed: RN19.6 (R3.2), U9.9 (A7)
unnamed: RN19.7 (R2.2), U9.8 (A6)
unnamed: RN19.8 (R1.2), U9.7 (A5)
unnamed: RN20.5 (R4.2), U10.6 (A4)
unnamed: RN20.6 (R3.2), U10.5 (A3)
unnamed: RN20.7 (R2.2), U10.4 (A2)
unnamed: RN20.8 (R1.2), U10.3 (A1)
unnamed: RN21.5 (R4.2), U10.10 (A8)
unnamed: RN21.6 (R3.2), U10.9 (A7)
unnamed: RN21.7 (R2.2), U10.8 (A6)
unnamed: RN21.8 (R1.2), U10.7 (A5)
unnamed: RN22.5 (R4.2), U11.6 (A4)
unnamed: RN22.6 (R3.2), U11.5 (A3)
unnamed: RN22.7 (R2.2), U11.4 (A2)
unnamed: RN22.8 (R1.2), U11.3 (A1)
unnamed: RN23.5 (R4.2), U11.10 (A8)
unnamed: RN23.6 (R3.2), U11.9 (A7)
unnamed: RN23.7 (R2.2), U11.8 (A6)
unnamed: RN23.8 (R1.2), U11.7 (A5)

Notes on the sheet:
Non 5V tolerant I/O: PC0-5, PA0-7, PB0-1, 5
Boot Loader Config
Volume Up & Down
UART Debug & Programming Header
Cortex Debug Header
KEY
Microcontroller
VCC Testing Header
Controller Ports & Level Conversion

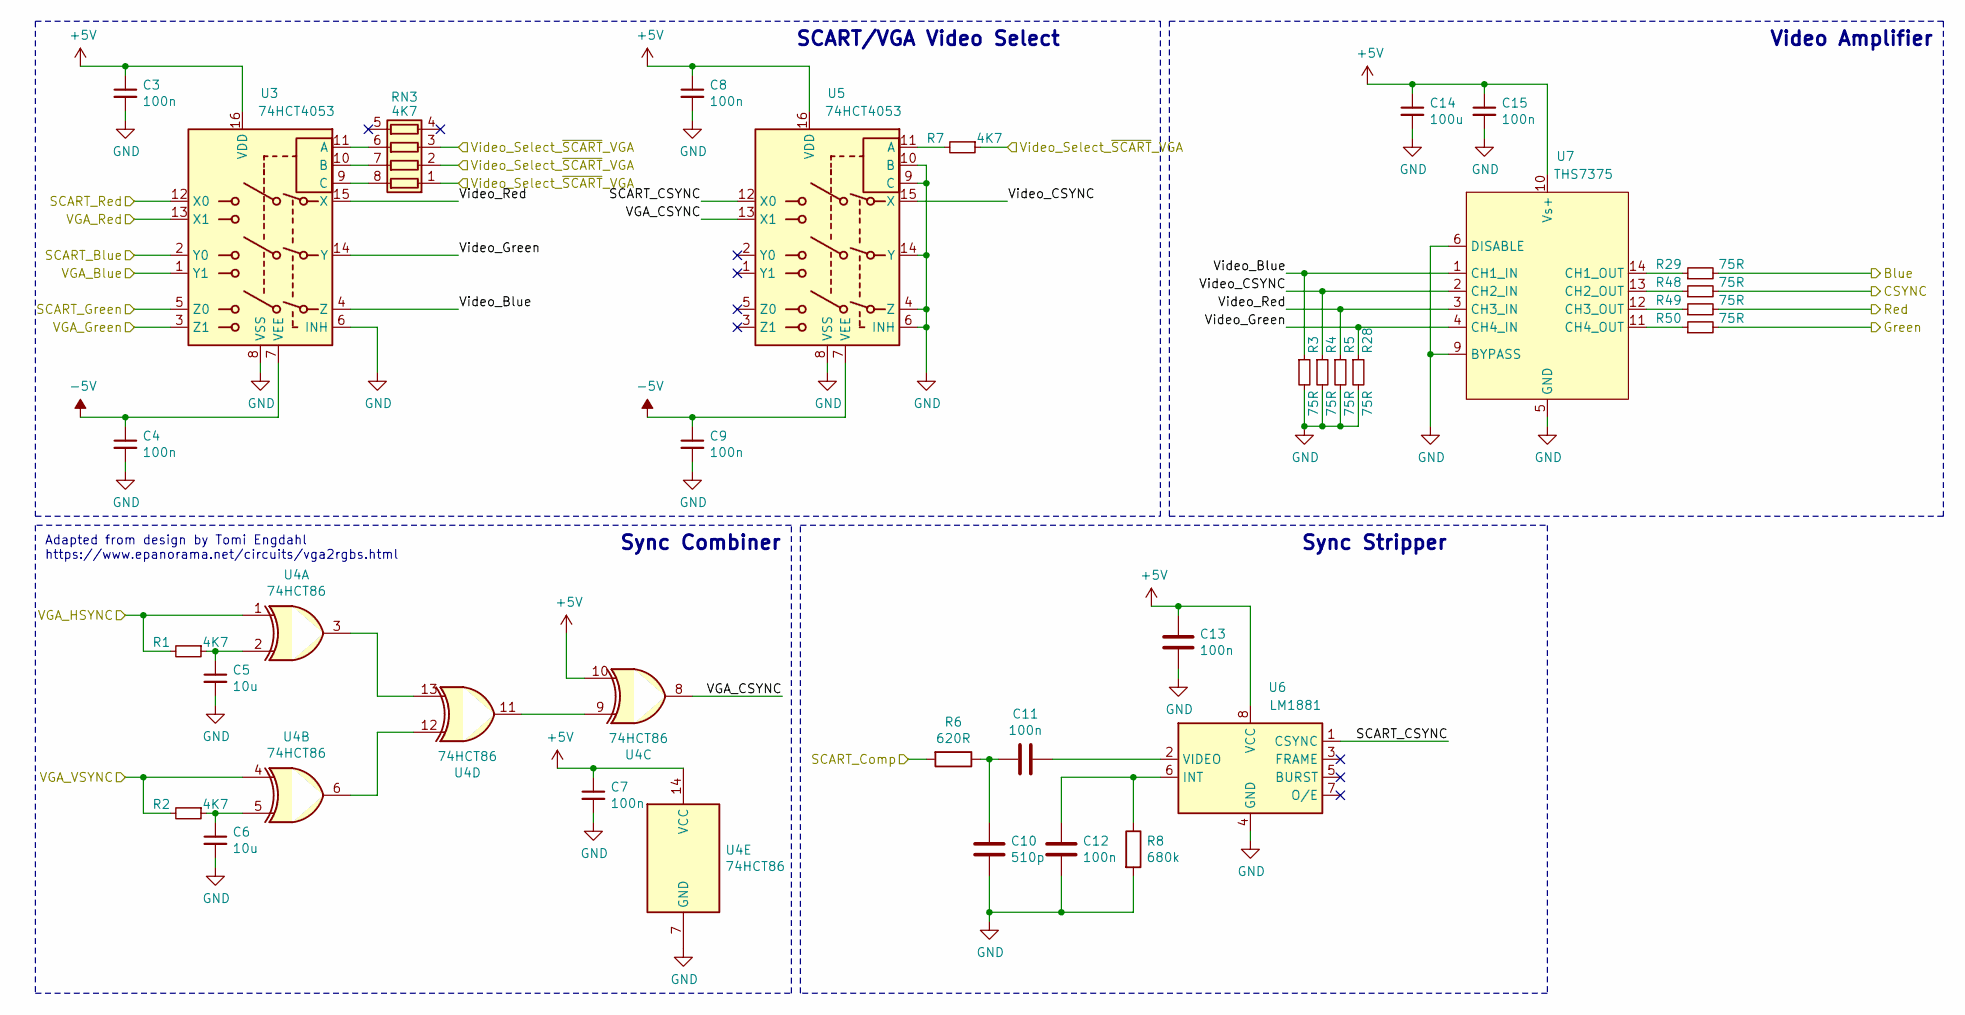
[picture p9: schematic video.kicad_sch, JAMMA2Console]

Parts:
C3, C4, C7, C8, C9, C11, C12, C13, C15: 100n; C_0603_1608Metric
C5, C6: 10u; C_0805_2012Metric
C10: 510p; C_0603_1608Metric
C14: 100u; C_1210_3225Metric
R1, R2, R7: 4K7; R_0603_1608Metric
R3, R4, R5, R28, R29, R48, R49, R50: 75R; R_0603_1608Metric
R6: 620R; R_0603_1608Metric
R8: 680k; R_0603_1608Metric
RN3: 4K7; R_Array_Convex_4x0603
U3, U5: 74HCT4053; SSOP-16_5.3x6.2mm_P0.65mm
U4: 74HCT86; SOIC-14_3.9x8.7mm_P1.27mm
U6: LM1881; SOIC-8_3.9x4.9mm_P1.27mm
U7: THS7375; TSSOP-14_4.4x5mm_P0.65mm

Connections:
+5V: C3.1, C7.1, C8.1, C13.1, C14.1, C15.1, U3.16 (VDD), U4.10, U4.14 (VCC), U5.16 (VDD), U6.8 (VCC), U7.10 (Vs+); also elsewhere on the board
-5V: C4.1, C9.1, U3.7 (VEE), U5.7 (VEE); also elsewhere on the board
/Composite_Sync: R48.2; also elsewhere on the board
/SCART_Blue: U3.2 (Y0); also elsewhere on the board
/SCART_Comp: R6.2; also elsewhere on the board
/SCART_Green: U3.5 (Z0); also elsewhere on the board
/SCART_Red: U3.12 (X0); also elsewhere on the board
/VGA_Blue: U3.1 (Y1); also elsewhere on the board
/VGA_Green: U3.3 (Z1); also elsewhere on the board
/VGA_HSYNC: R1.2, U4.1; also elsewhere on the board
/VGA_Red: U3.13 (X1); also elsewhere on the board
/VGA_VSYNC: R2.2, U4.4; also elsewhere on the board
/Video/SCART_CSYNC: U5.12 (X0), U6.1 (CSYNC)
/Video/VGA_CSYNC: U4.8, U5.13 (X1)
/Video/Video_Blue: R3.1, U3.4 (Z), U7.1 (CH1_IN)
/Video/Video_CSYNC: R4.1, U5.15 (X), U7.2 (CH2_IN)
/Video/Video_Green: R28.1, U3.14 (Y), U7.4 (CH4_IN)
/Video/Video_Red: R5.1, U3.15 (X), U7.3 (CH3_IN)
/Video_Blue: R29.2; also elsewhere on the board
/Video_Green: R50.2; also elsewhere on the board
/Video_Red: R49.2; also elsewhere on the board
/Video_Select_~SCART~_VGA: R7.1, RN3.1 (R1.1), RN3.2 (R2.1), RN3.3 (R3.1); also elsewhere on the board
GND: C3.2, C4.2, C5.2, C6.2, C7.2, C8.2, C9.2, C10.2, C12.2, C13.2, C14.2, C15.2, R3.2, R4.2, R5.2, R8.2, R28.2, U3.6 (INH), U3.8 (VSS), U4.7 (GND), U5.4 (Z), U5.6 (INH), U5.8 (VSS), U5.9 (C), U5.10 (B), U5.14 (Y), U6.4 (GND), U7.5 (GND), U7.6 (DISABLE), U7.9 (BYPASS); also elsewhere on the board
unnamed: C5.1, R1.1, U4.2
unnamed: C6.1, R2.1, U4.5
unnamed: C10.1, C11.2, R6.1
unnamed: C11.1, U6.2 (VIDEO)
unnamed: C12.1, R8.1, U6.6 (INT)
unnamed: R7.2, U5.11 (A)
unnamed: R29.1, U7.14 (CH1_OUT)
unnamed: R48.1, U7.13 (CH2_OUT)
unnamed: R49.1, U7.12 (CH3_OUT)
unnamed: R50.1, U7.11 (CH4_OUT)
unnamed: RN3.6 (R3.2), U3.11 (A)
unnamed: RN3.7 (R2.2), U3.10 (B)
unnamed: RN3.8 (R1.2), U3.9 (C)
unnamed: U4.9, U4.11
unnamed: U4.6, U4.12
unnamed: U4.3, U4.13

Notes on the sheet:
Adapted from design by Tomi Engdahl https://www.epanorama.net/circuits/vga2rgbs.html
Sync Combiner
SCART/VGA Video Select
Sync Stripper
Video Amplifier

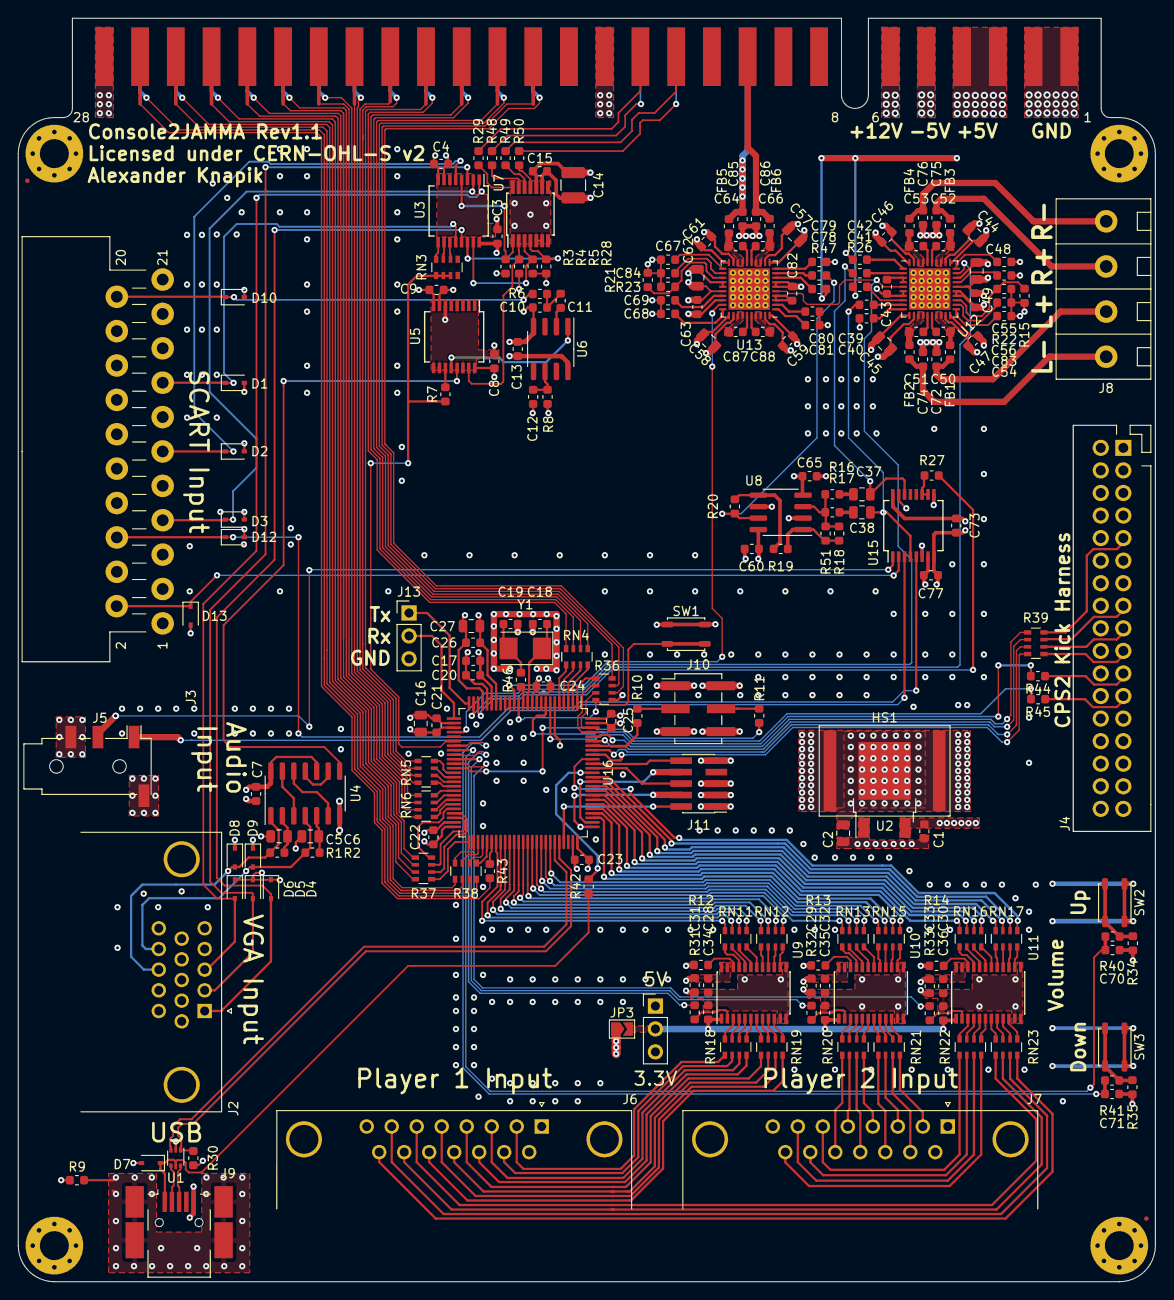
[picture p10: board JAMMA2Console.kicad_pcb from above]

Board: 4 copper layers, 126.0 x 140.0 mm, 211 parts (0 on the bottom side), 295 nets.

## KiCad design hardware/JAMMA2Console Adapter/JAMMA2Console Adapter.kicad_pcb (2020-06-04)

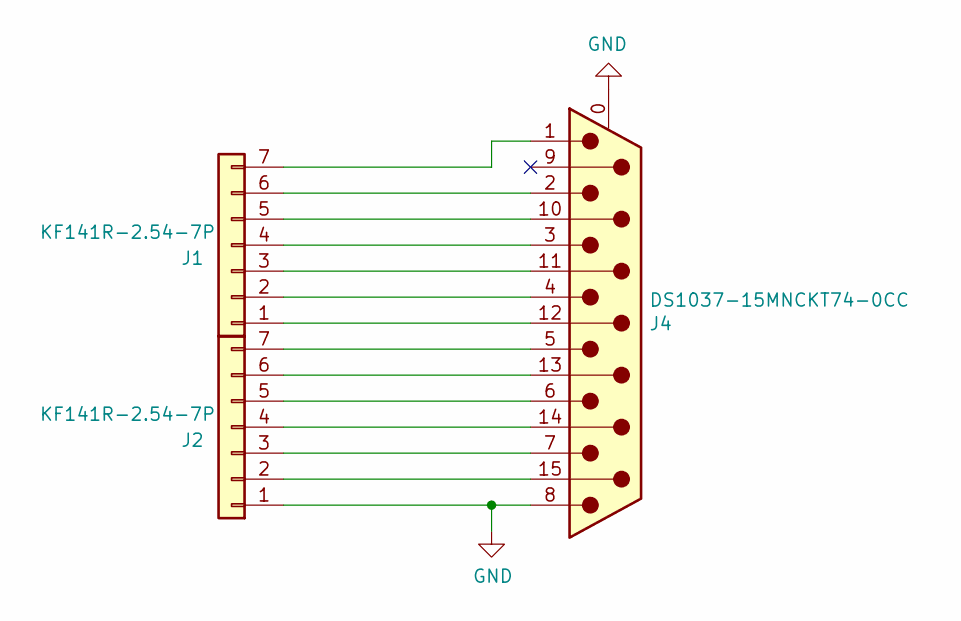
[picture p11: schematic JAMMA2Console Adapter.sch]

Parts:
J1, J2: KF141R-2.54-7P; CixiKefa_KF141R-2.54-7P_1x7_P2.54mm_Horizontal
J4: DS1037-15MNCKT74-0CC; DSUB-15_Male_Horizontal_P2.77x2.84mm_EdgePinOffset8.10mm_Ho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

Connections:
GND: J2.1, J4.0 (PAD), J4.8
unnamed: J1.1, J4.12
unnamed: J1.2, J4.4
unnamed: J1.3, J4.11 (P111)
unnamed: J1.4, J4.3
unnamed: J1.5, J4.10
unnamed: J1.6, J4.2
unnamed: J1.7, J4.1
unnamed: J2.2, J4.15
unnamed: J2.3, J4.7
unnamed: J2.4, J4.14
unnamed: J2.5, J4.6
unnamed: J2.6, J4.13
unnamed: J2.7, J4.5

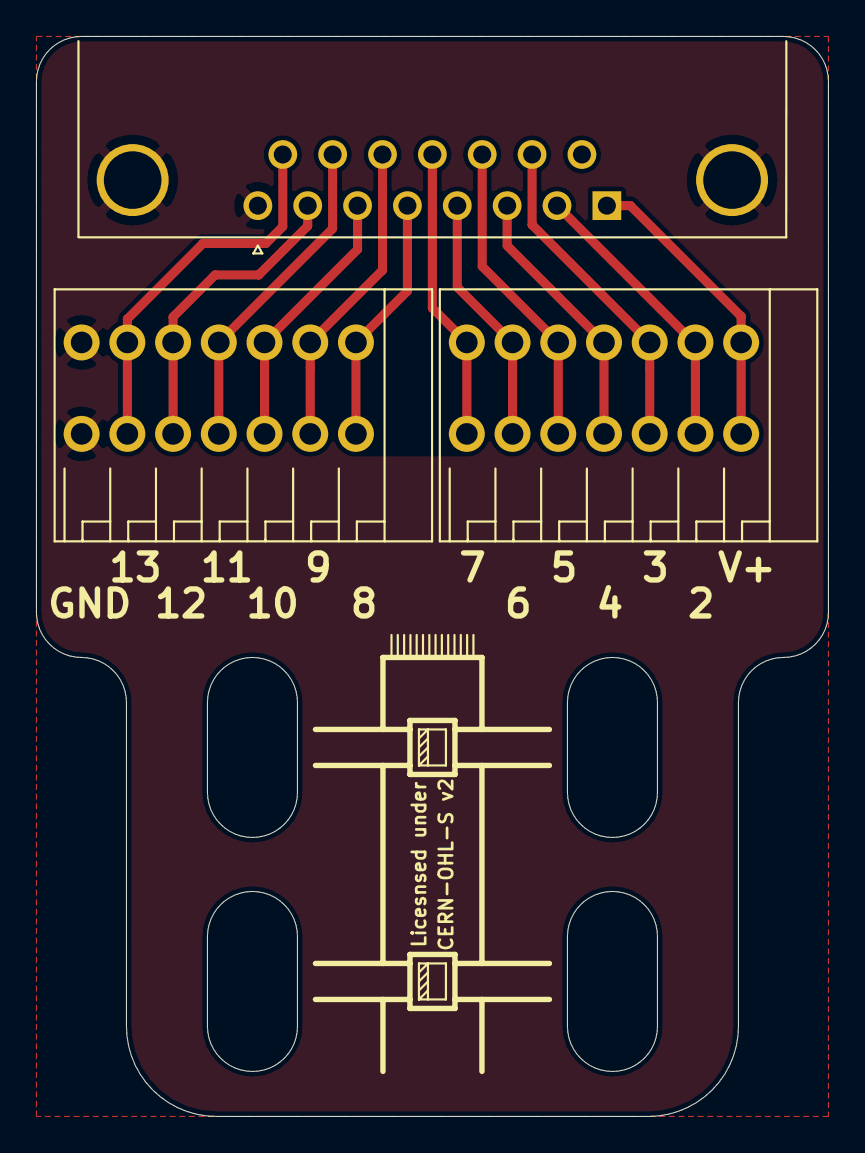
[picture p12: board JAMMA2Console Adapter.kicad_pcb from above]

Board: 2 copper layers, 44.0 x 60.0 mm, 3 parts (0 on the bottom side), 14 nets.

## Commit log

2019-12-19 Initialising repo
    [JAMMA2Console.kicad_pcb, JAMMA2Console.sch]
2019-12-28 Updating work so far. Mainly just to set up an online repository for everything, so I can switch to my desktop
2020-02-02 Just updating on how things are going. Its pretty messy at the moment, but in the same time I'm not even close to finishing the schematic. I'm going to split up the schematic into different pages for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
    [JAMMA2Console.sch]
2020-02-29 More work on various schematic files, added footprint for the speaker out terminal connectors.
    [JAMMA2Console.kicad_pcb, JAMMA2Console.sch, audio.sch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]
2020-04-06 Schematic mainly done. Working on PCB layout in isolated blocks.
    [JAMMA2Console.sch, audio.sch, digital.sch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]
2020-04-19 Completing the functionality of PCB layout. Require silkscreen placement still, though.
    [JAMMA2Console.kicad_pcb, JAMMA2Console.sch, audio.sch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]
2020-04-21 Updating silkscreen placement and fixing up a few issues with layout. Still require via stitching to be done. Adding CERN OHL S license in hardware folder.
    [JAMMA2Console.kicad_pcb, JAMMA2Console.sch, audio.sch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]
2020-04-26 Completing layout & minor edits for the main PCB. Added a project for the adapters to plug controllers into.
    [JAMMA2Console Adapter.kicad_pcb, JAMMA2Console Adapter.sch, JAMMA2Console.kicad_pcb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]
2020-06-04 Started major rework on the Audio section (chose the wrong amplifier as it can't drive 4Ohm loads) Moved over to nightly Kicad v 5.9 versions. Was a mistake to do, but will look into reverting anothe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
    [JAMMA2Console Adapter.kicad_pcb, JAMMA2Console Adapter.sch, JAMMA2Console.kicad_pcb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]
2020-06-04 Removing files that will break the project in v5.99 if opened
    [JAMMA2Console.sch, audio.sch, digital.sch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]
2020-08-16 Pushing work I did a few months ago and I forgot to push. Identified some mistakes which I'll fix in a future commit.
    [JAMMA2Console.kicad_pcb, JAMMA2Console.kicad_sch, audio.kicad_sch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]
2020-08-16 Updated the schematic & layout to fix the heat sink net issues with the 3v3 regulator.
    [JAMMA2Console.kicad_pcb, JAMMA2Console.kicad_sch, digital.kicad_sch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]
2020-08-25 Adding extra info on todo list about USB impedance issues on Rev 1.0
    [JAMMA2Console.kicad_pcb, JAMMA2Console.kicad_sch, digital.kicad_sch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]

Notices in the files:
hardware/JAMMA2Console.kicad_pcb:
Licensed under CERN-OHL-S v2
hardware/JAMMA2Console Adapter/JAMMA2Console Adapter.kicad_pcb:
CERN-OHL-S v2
